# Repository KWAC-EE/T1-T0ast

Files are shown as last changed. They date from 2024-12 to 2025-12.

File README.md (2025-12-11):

# T1-T0ast
Mini-ITX drop-in motherboard for the CM5.

##Rev X4 Issue notice!¡!1!##
If building to RevX4 design spec, depopulate FB6. This component may short -12VDC on PSUs that supply this rail (-12vDC is unused at this time)



Designed with the intention of allowing legacy Sata, PCIE, and ATX/ITX equipment to find a useful home.
Primarily selected components from TI in advance due to open documentation & domestic sourcing.

# Project design files
PCBAs are designed in Altium 22 & 25. This is a paid software platform for professionals, and viewer licenses can be requested from the developers.
Now that the design is roughly complete, I will spend some time learning how to port the design directly into KiCad or EasyEDA for more direct access to hobbyists.
Design references can also be found as PDFs for those who wish to rebuild segments of the design themselves.

# PCBA exports/ Manufacturer files
Designs have been exported as Gerbers with Pick&Place & BOM files such that they may be fully assembled by prototypers such as JLC-PCB, PCB-Way and the like.
Simply upload the zipped project export folder for the PCB, then the internal XLXS/CSV component-level assembly.
Component selection of passives was left generic to allow for flexible sourcing. ICs and other specified parts have a parameter called "LCSC PN", which can be used to preorder components from either LCSC or JLCPCB prior to placing an assembly order.
Some footprints are custom, and part number left unmatched. These have been hand-soldered inhouse or are used for debugging, and I dont recommend having a board house manage these for cost or quality reasons.

# Firmware & Software support
All Hubs are plug&play, and are meant to function with the Raspberry pi CM5 without manual driver installation.
Direct IO is passed from the CM to plug headers without modification.
USB-Audio codec has integrated drivers in Raspberry Pi OS, and Auto-installs via Windows update if accessible.
USB-SATA Bridge requires flashing to the NAND module prior to operation. Hex/bin files to do so are available in corresponding folder.

# License
Copyright Kurt Widhalm/@KWAC-EE 2025
This source describes Open Hardware and is licensed under the CERN-OHL-P v2

You may redistribute and modify this documentation and make products using it under the terms of the CERN-OHL-P v2 (https:/cern.ch/cern-ohl). This documentation is distributed WITHOUT ANY EXPRESS OR IMPLIED WARRANTY, INCLUDING OF MERCHANTABILITY, SATISFACTORY QUALITY AND FITNESS FOR A PARTICULAR PURPOSE. Please see the CERN-OHL-P v2 for applicable conditions

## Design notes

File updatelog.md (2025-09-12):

**2/12/2025**



First rev arrived and I've started preliminary testing. So far, I'm able to confirm that direct passthrough IO (LAN, HDMI, SD Card) function as intended.

HDMI1 (which had a redriver IC) does not function directly, and i'm not sure if its my config file or if i screwed up the icrcuit. Either way, i might omit the redriver from rev x2.

Sadly, my SATA bridges lack the requisite Eeprom to store the firmware required to initialize, so that segement could not be tested. Separate prototypes for this segment are inbound.

The USB Hub chosen for Rev x1 claims to be USB2, but that turns out to be on the low end of the spec (12Mbps) and I wasn't able to get it to populate.

My power scheme (24pin ATX + 4-pin) seems to be working as intended. The momentary switch is superceded by a relay to keep the PSU active once the CM is powered on. At this time, Safe powe-down operation can only be completed from the desktop. Currently powering via Pico-PSU & 12VDC supply for bench setup, but larger PCIE cards/ Sata drives will likely require increased wattage and stability of a full supply.

I've been testing with a CM4 and Radxa-CM5 while i wait for my pi Cm5 (on backorder) so behavior might change when I'm able to switch to the real deal.

**3/7/2025**
Rev X2 updates based on sample testing have been laid out. Development kits for 7x USB2 hub are inbound. SATA bridges have been corrected based on feedback from TI.

Due to differences in startup behavior between rPi & Radxa CM5, hardwired delay circuits have been added to latching relays, and power button/reset have been made discrete.

Previous assembly process called out ENIG for PCB; will switch to HASL to save cost

**4/25/2025**
Rev X3 samples received and modified during testing.



All IO EXCEPT for the M.2 & Sata behave as intended.

TUSB9261 GRST circuit needed to be modified to allow for passive reset operation during boot. Firmware for these chips also needed to be applied externally to their requisiste SPI flash modules with a clip programmer, as TI no longer supports the flashing utility in Linux.

The TUSB8020 Hub used to drive the USB-SATA bridges is having issues. lsusb shows internal PID 8027 enumerated, but not the 8025 segment. For some reason, this means the downstream ports aren't initialised by the system.
I can't tell at the moment if this is due to a hardware fault in the pinout of the chip or the pi, or if theres too much interference from running the DP/DM traces under nearby AC caps.

The Sata bridge used for the M.2 slot initialises just fine, but I can't seem to get it to recognise an A+M key sata drive. Maybe something in the 3.3V power scheme? I'll shunt over the resettable fuse to see if it is just dropping too much voltage.

Tested several simple PCIe devices in the x16 slot like a SATA expansion and USB-C expansion card, and both are recognised by lspci. Both seem to function as intended, but thats at PCIe gen 2 speeds (haven't modified the config to try Gen 3).
A low end graphics (GT210) card i dropped in wasn't recognised by lspci, so I can't vouch for that kind of implementation just yet.

Feels like i'm nearing the finish line. In any case, the X3 does most of what i need for work purposes, so I may spend some time away from development.

**5/8/2025**
 Rev X4 changes underway
 
I've removed the manually timed reset circuits for the latching relay and Sata bridges, and made them passive. The leveling capacitors on the TUSB9261s are larger than recommended, with the intention of delaying reset until 2x the time of their host USB3 hubs.

I've also removed & replaced the TUSB8020 with an 8041 for the sata bridges, routing the spare USB3 lanes to a FP-IO header.

Per TI's recommendations, I've added AC coupling caps on BOTH the RX & TX lines between the pi and hubs. The IO board for the CM5 lacks these and seem to function ok, but in the interest of Giving myself an out, i will at least include the pads (couple replace RX caps with 0ohm resistors if deemed unnecessary)

Biffed the firmware flashing process and my flashing tool during debugging, hopefully will receive replacement chip-clips soon. Ideally, i could pre-flash the spi modules before doing a full build, but the bridges on the full board dont seem to like receiving rev 1.06 firmware binaries as much as their discrete counterparts on my dev kits. what this means is that I will need to port windows to a CM5 (WoP project has thankfully done enough for me to try this) and use the native TI Flash-burner utility to do this within the system.

but holy hell, i reran the costs for this dev build, and its over a grand for 5 boards from JLCPCB with the nonsensical tarrifs (domestics are much higher and have MOQ of 10, which i think is even more wasteful if a batch is a dud).
If you don't see an update from me after this, its because i've mothballed development until a sane adult is in charge.

**6/4/2025**
Well, here i am. Bit the bullet. one more go from me, fam

Rev X4 with some IO modifications is in flight. If this doesn't work, i entrust the next weary traveler to pick up the torch and carry on.

results to follow

**6/30/2025**
Works as well as I can reasonably hope. had to remove the AC caps to leave both RX & TX floating on the hub which drives the 2 sata bridges.

Been troubleshooting this issue so long, with tickets to both TI & The pi forums, and i cant find a solution to the USB3 enumeration issue.

I'll package and release the current hardware production files once I daily drive this model for a bit. Sent a sample for review, so if that brought you here, welcome!

Don't take my design as gospel, but it is all at least 98% functional, from the power regulation to the IO expanders and adapters. If you have a project which could use part of this design, adherent to the open-source nature of the project as it is, have at it.

If you need design resources, or you're interested in seeing which hardware can be made compatible with this platform, check out my other repositories.

**9/12/2025**
The whole thing works. I am an idiot.

The CM5's that I'd been using for development and testing were all damaged in the same location by me, and I never noticed until an rPi dev pointed out that part of the usb3 circuit had components close to a mounting hole.

After NOT fucking up a fresh CM and installing it fresh out of the box, everything worked as designed. so there. I'll be done.

Pending review from some connoisseurs, I'll uprev and package the files in an official release, but I'm not puting myself under any pressure to do so.

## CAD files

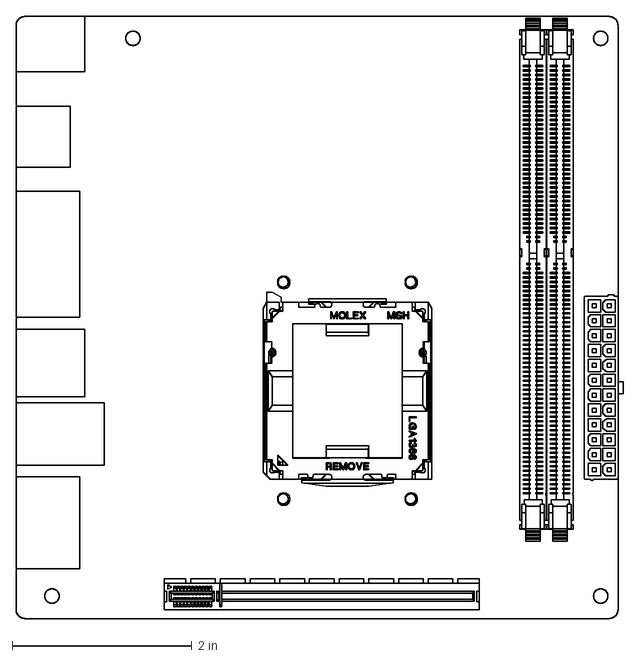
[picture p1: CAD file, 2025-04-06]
Altium Project/X1/Mini-ITX Mobo.step.DXF
6.75 x 6.69 in

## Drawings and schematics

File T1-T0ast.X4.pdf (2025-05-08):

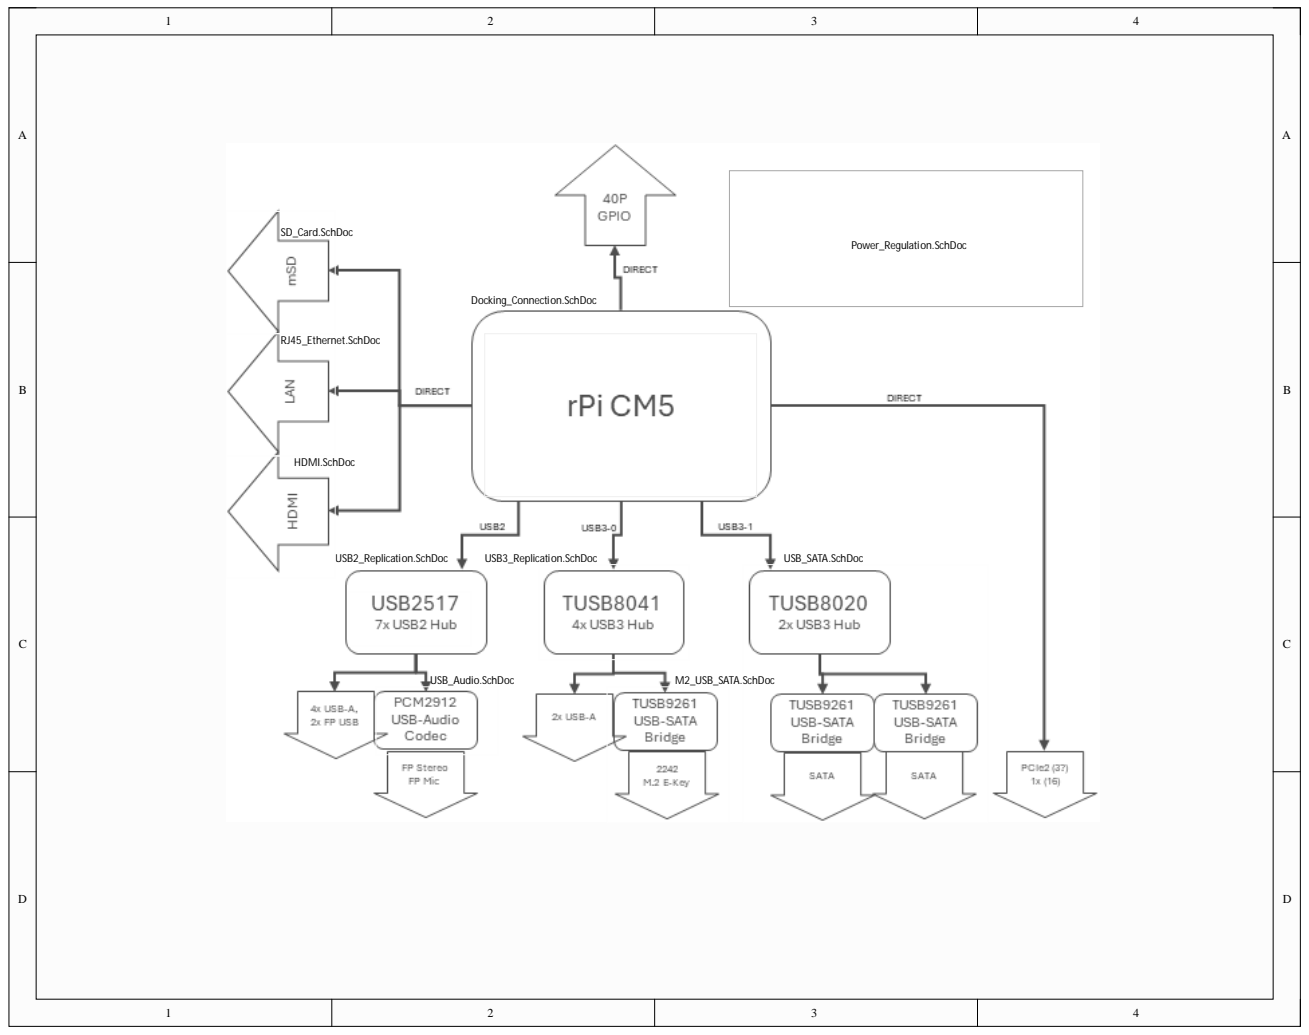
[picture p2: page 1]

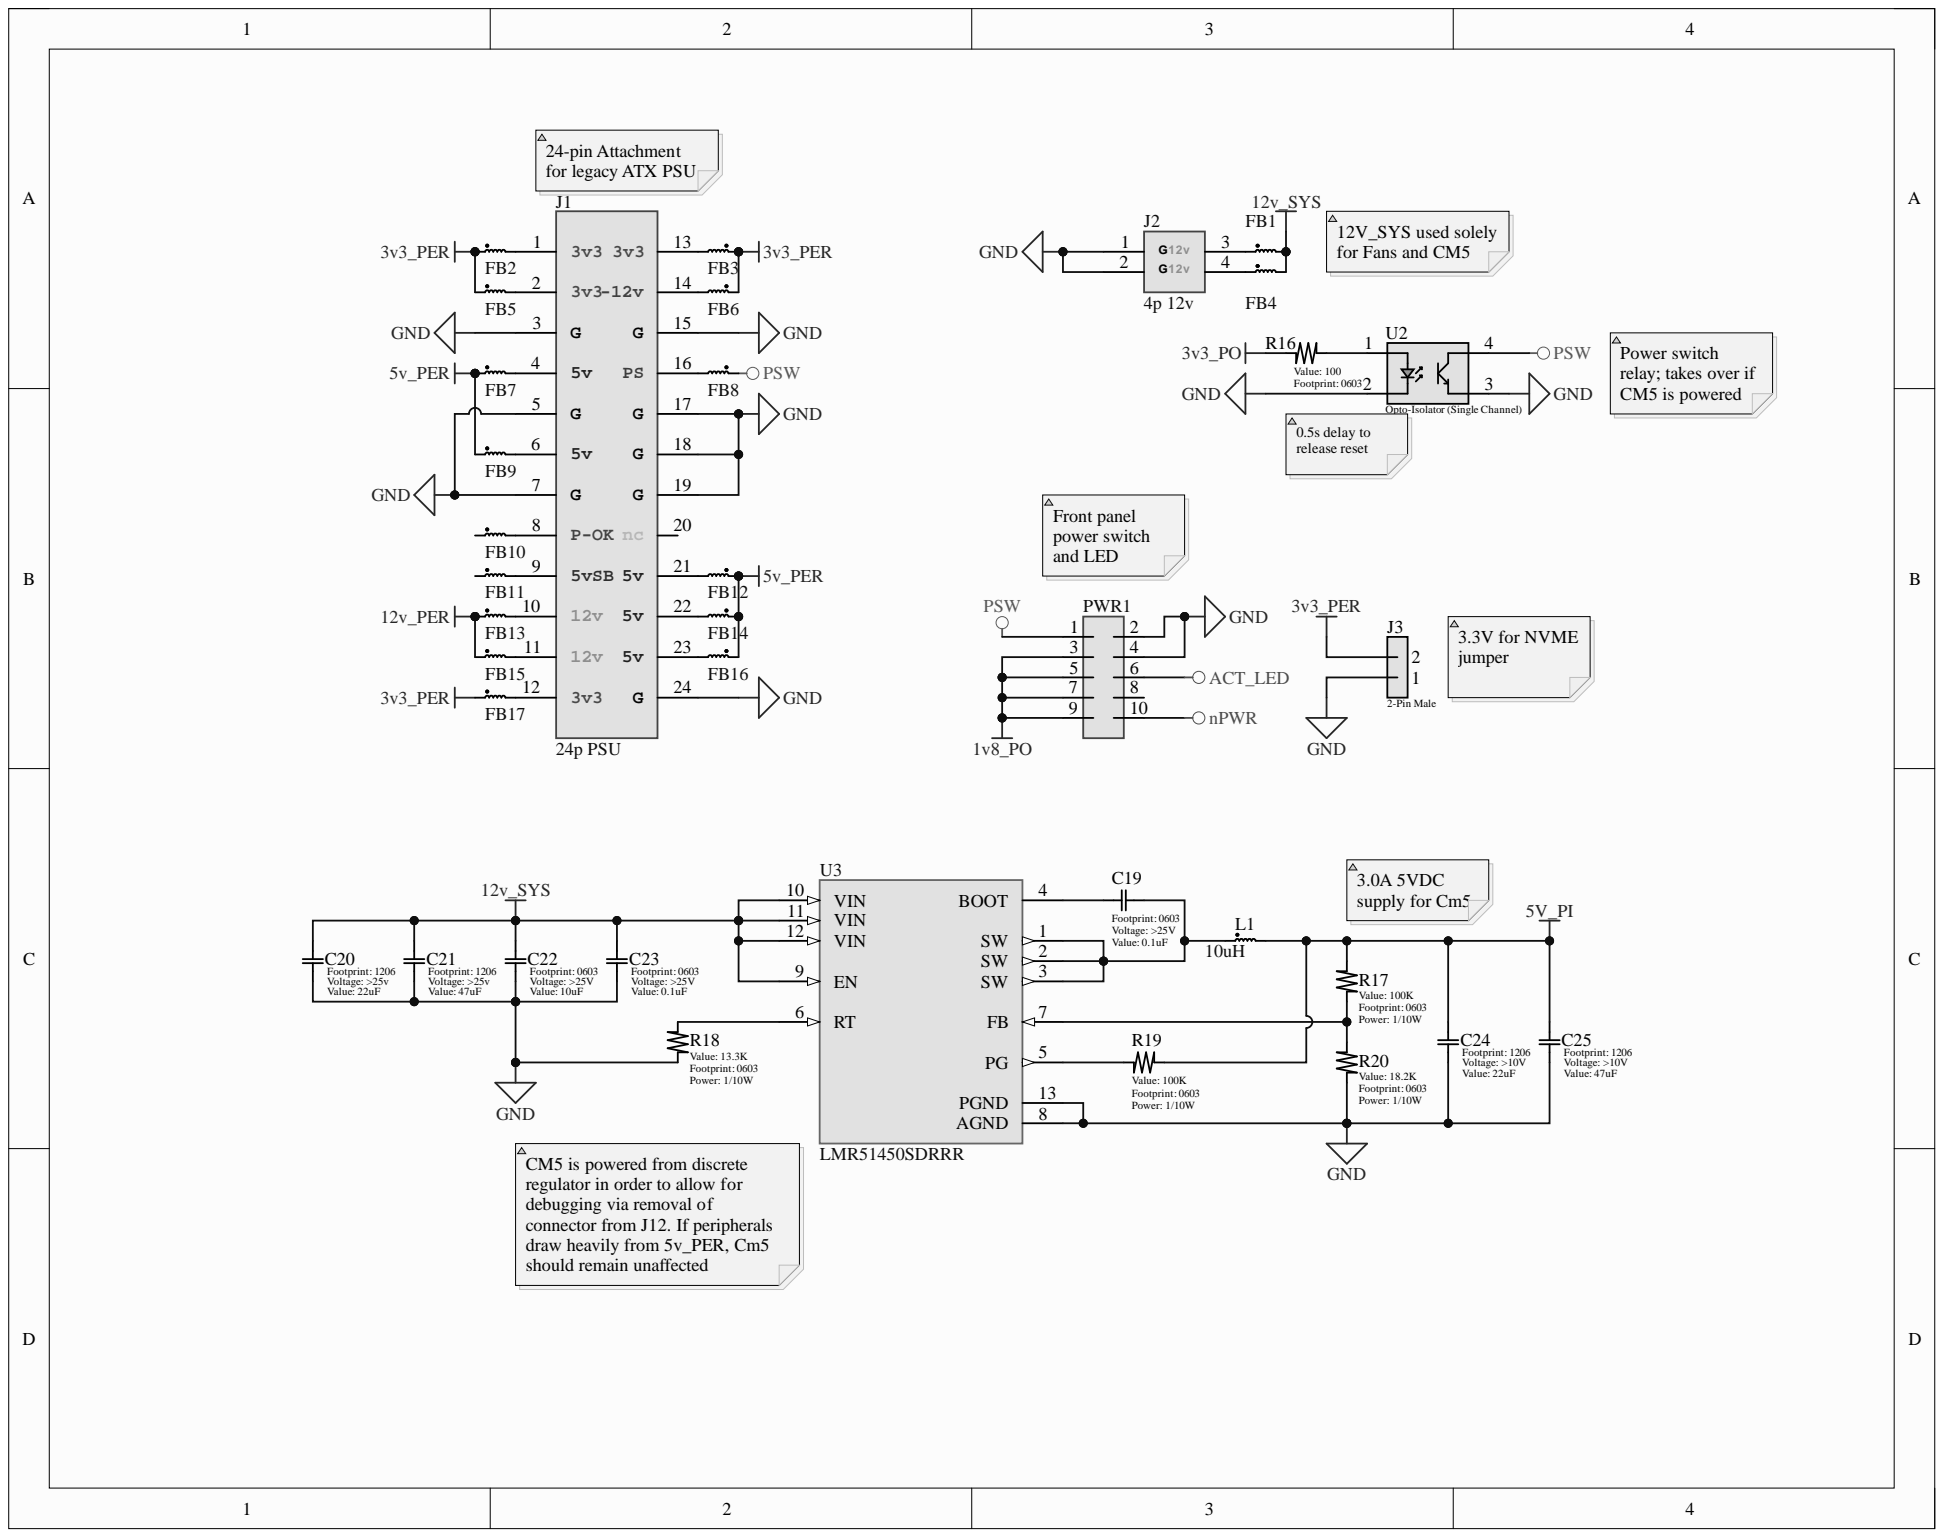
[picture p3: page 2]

24-pin Attachment
for legacy ATX PSU

Power switch
relay; takes over if
CM5 is powered

Opto-Isolator (Single Channel)

CM5 is powered from discrete
regulator in order to allow for
debugging via removal of
connector from J12. If peripherals
draw heavily from 5v_PER, Cm5
should remain unaffected

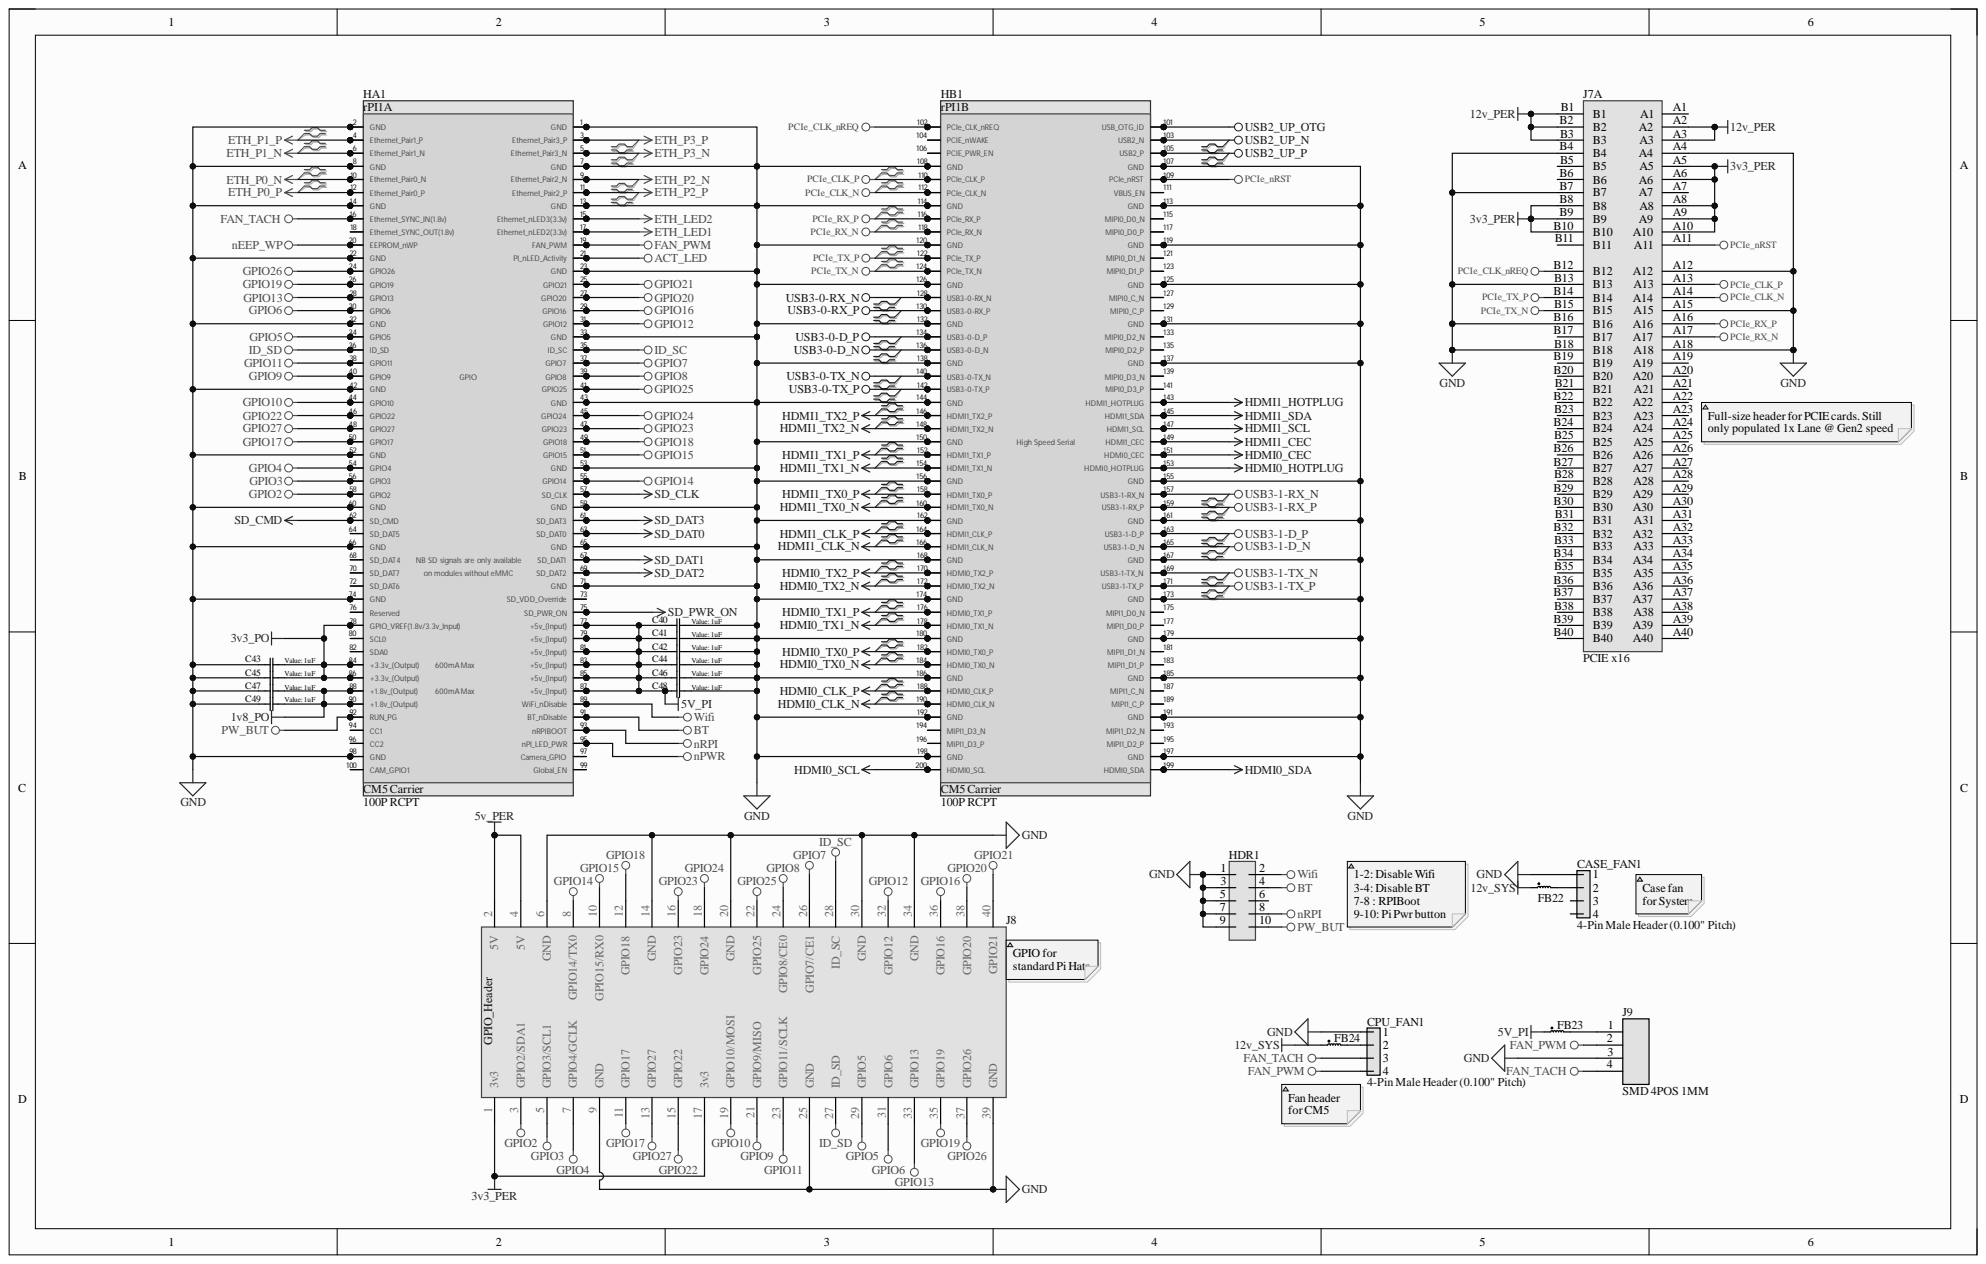
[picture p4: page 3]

PCIe_CLK_nREQ | B8 B8

Full-size headerfor PCIEcards. Still
only populated 1x Lane @ Gen2 speed

NB SD signals are only available
on modules without eMMC

4-Pin Male Header(0.100" Pitch)

GPIO3 GPIO4 | GPIO27 GPIO22

GPIO9 GPIO11 | GPIO6

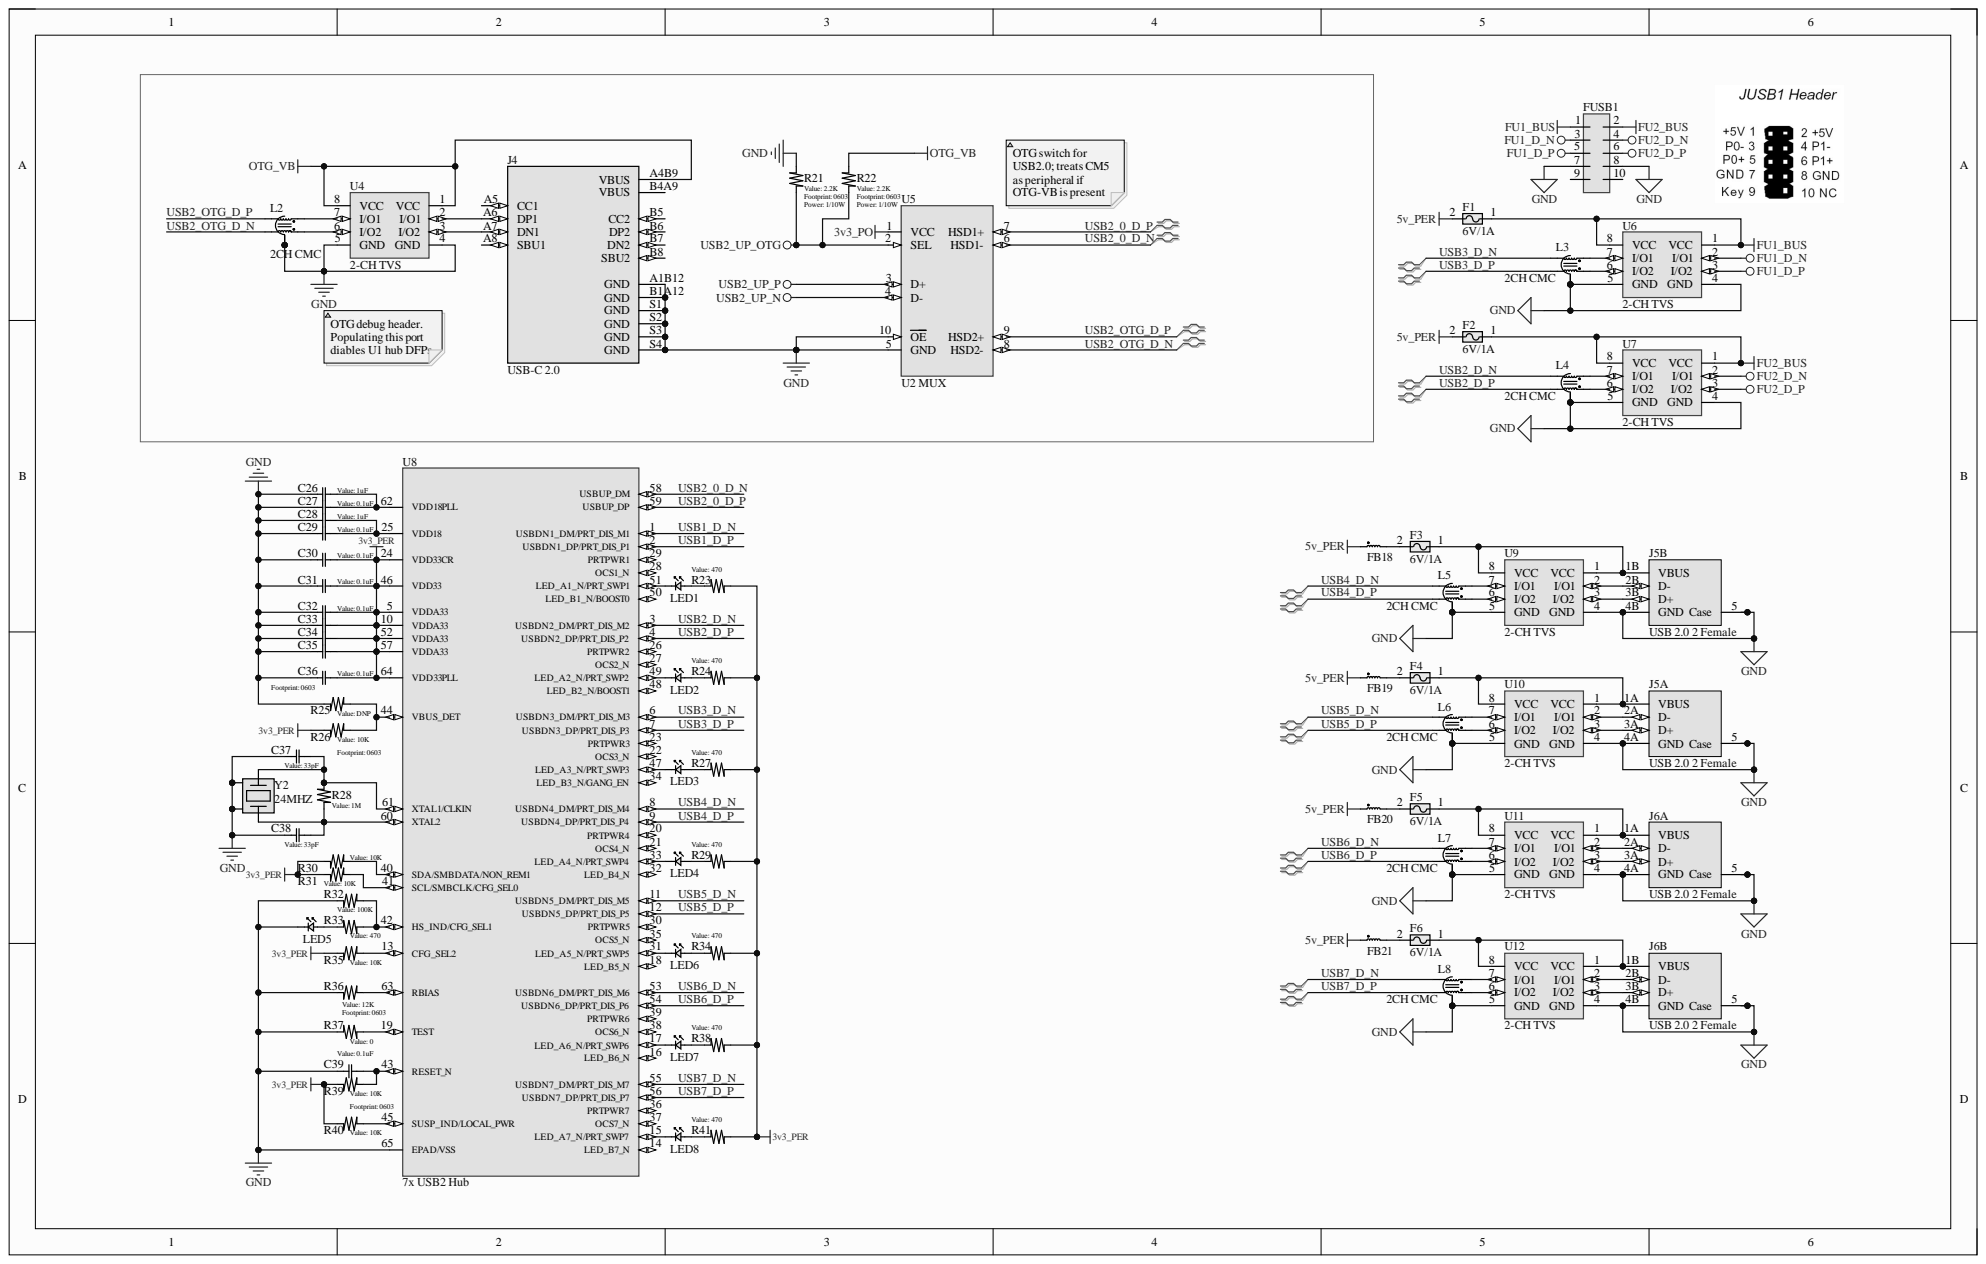
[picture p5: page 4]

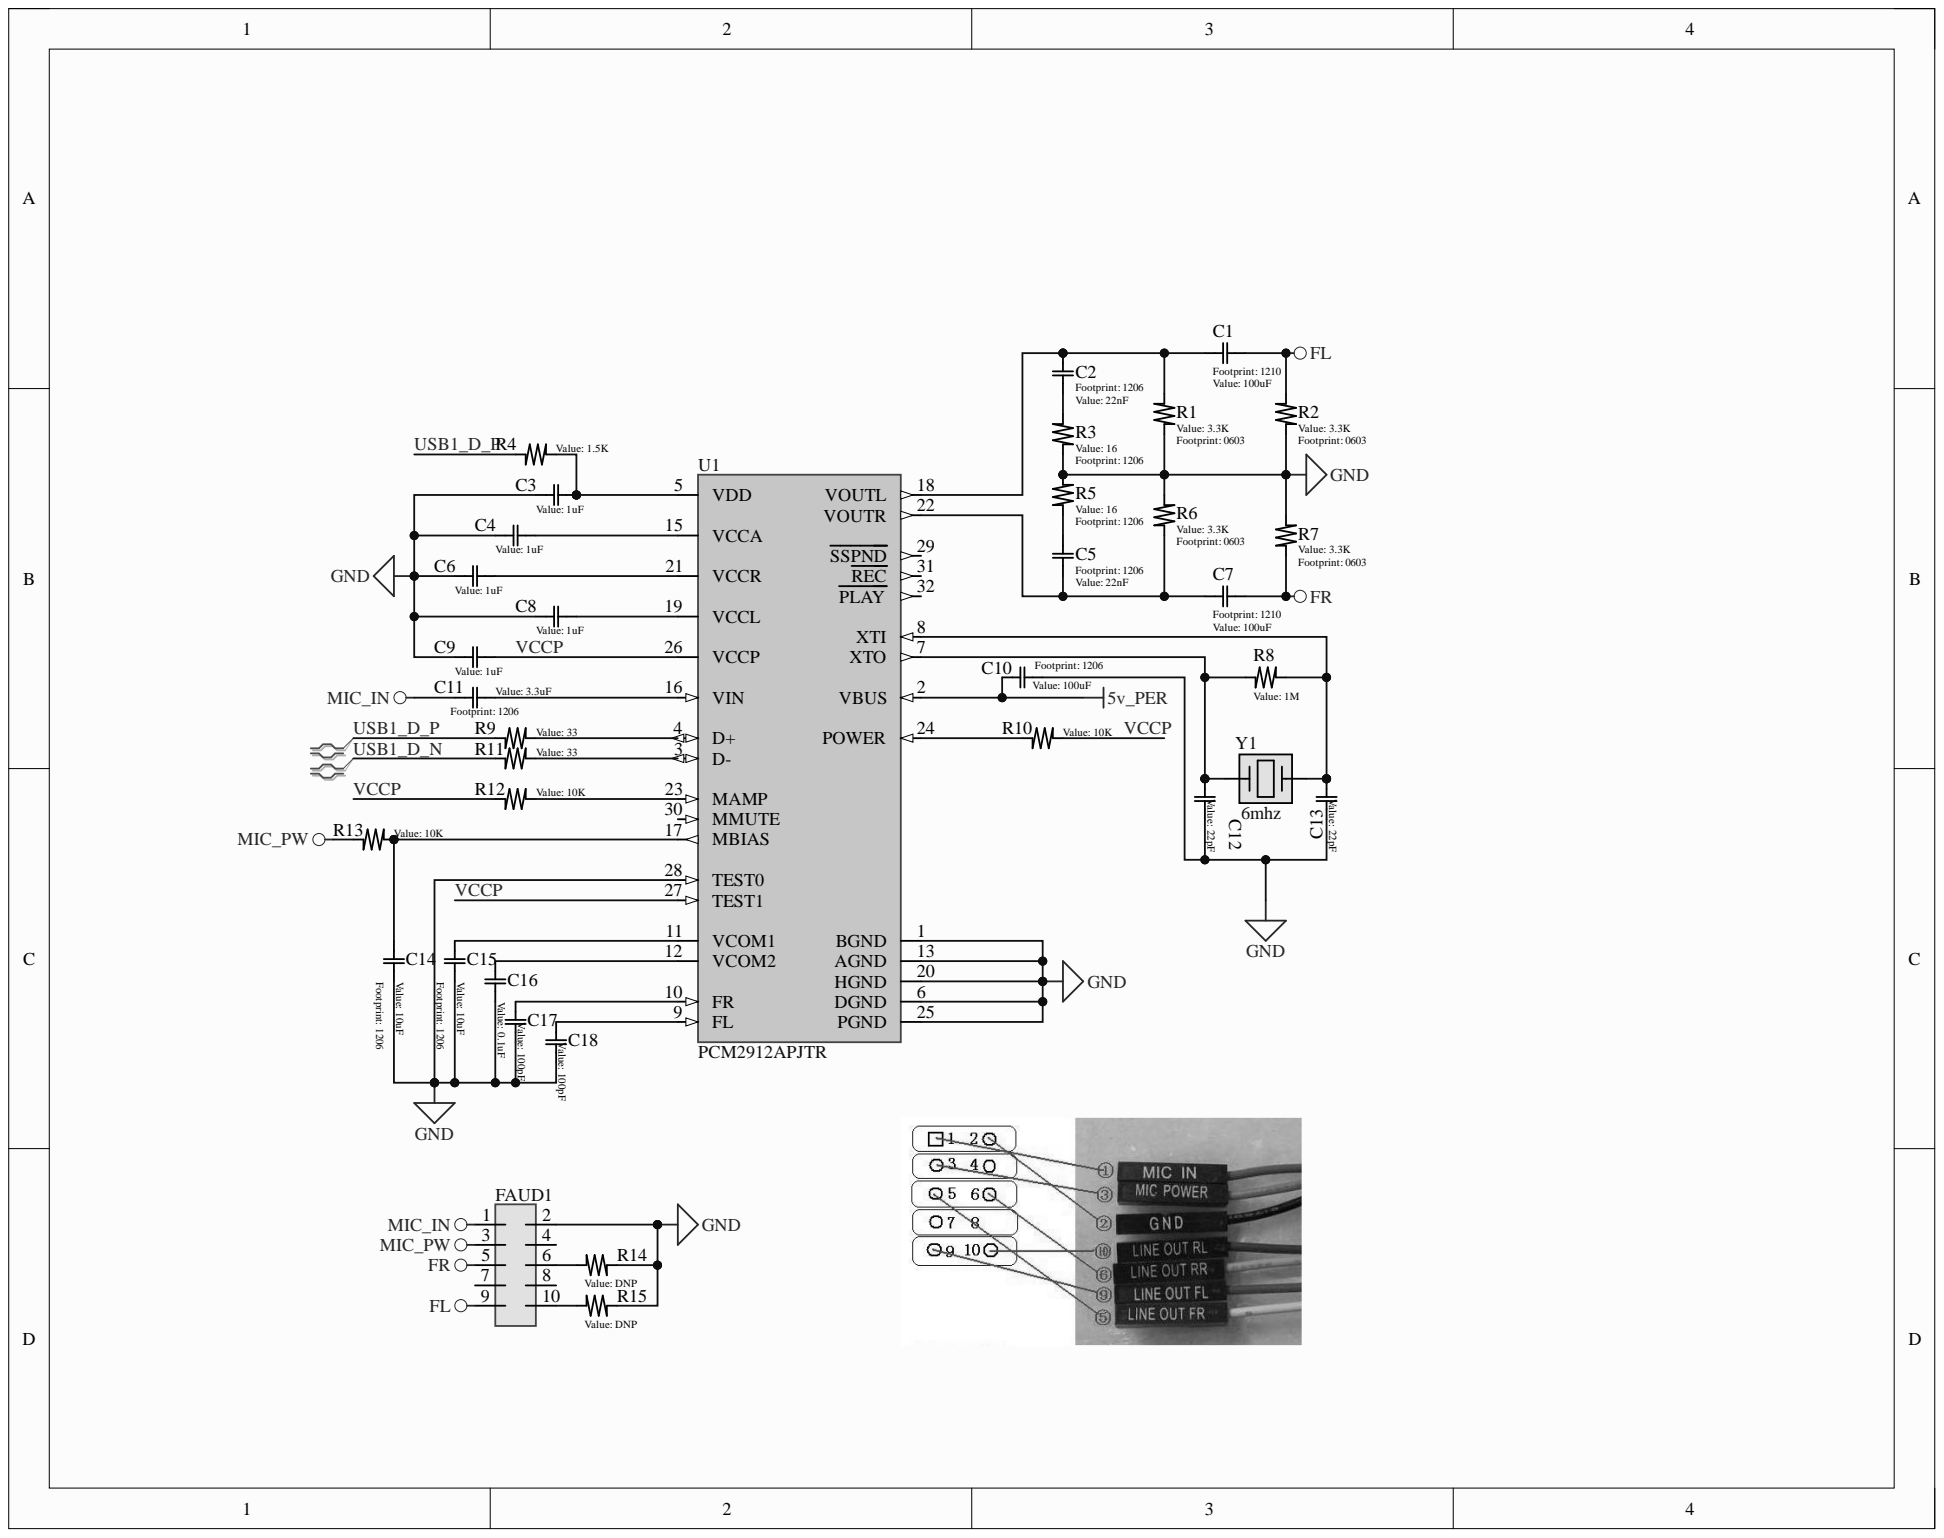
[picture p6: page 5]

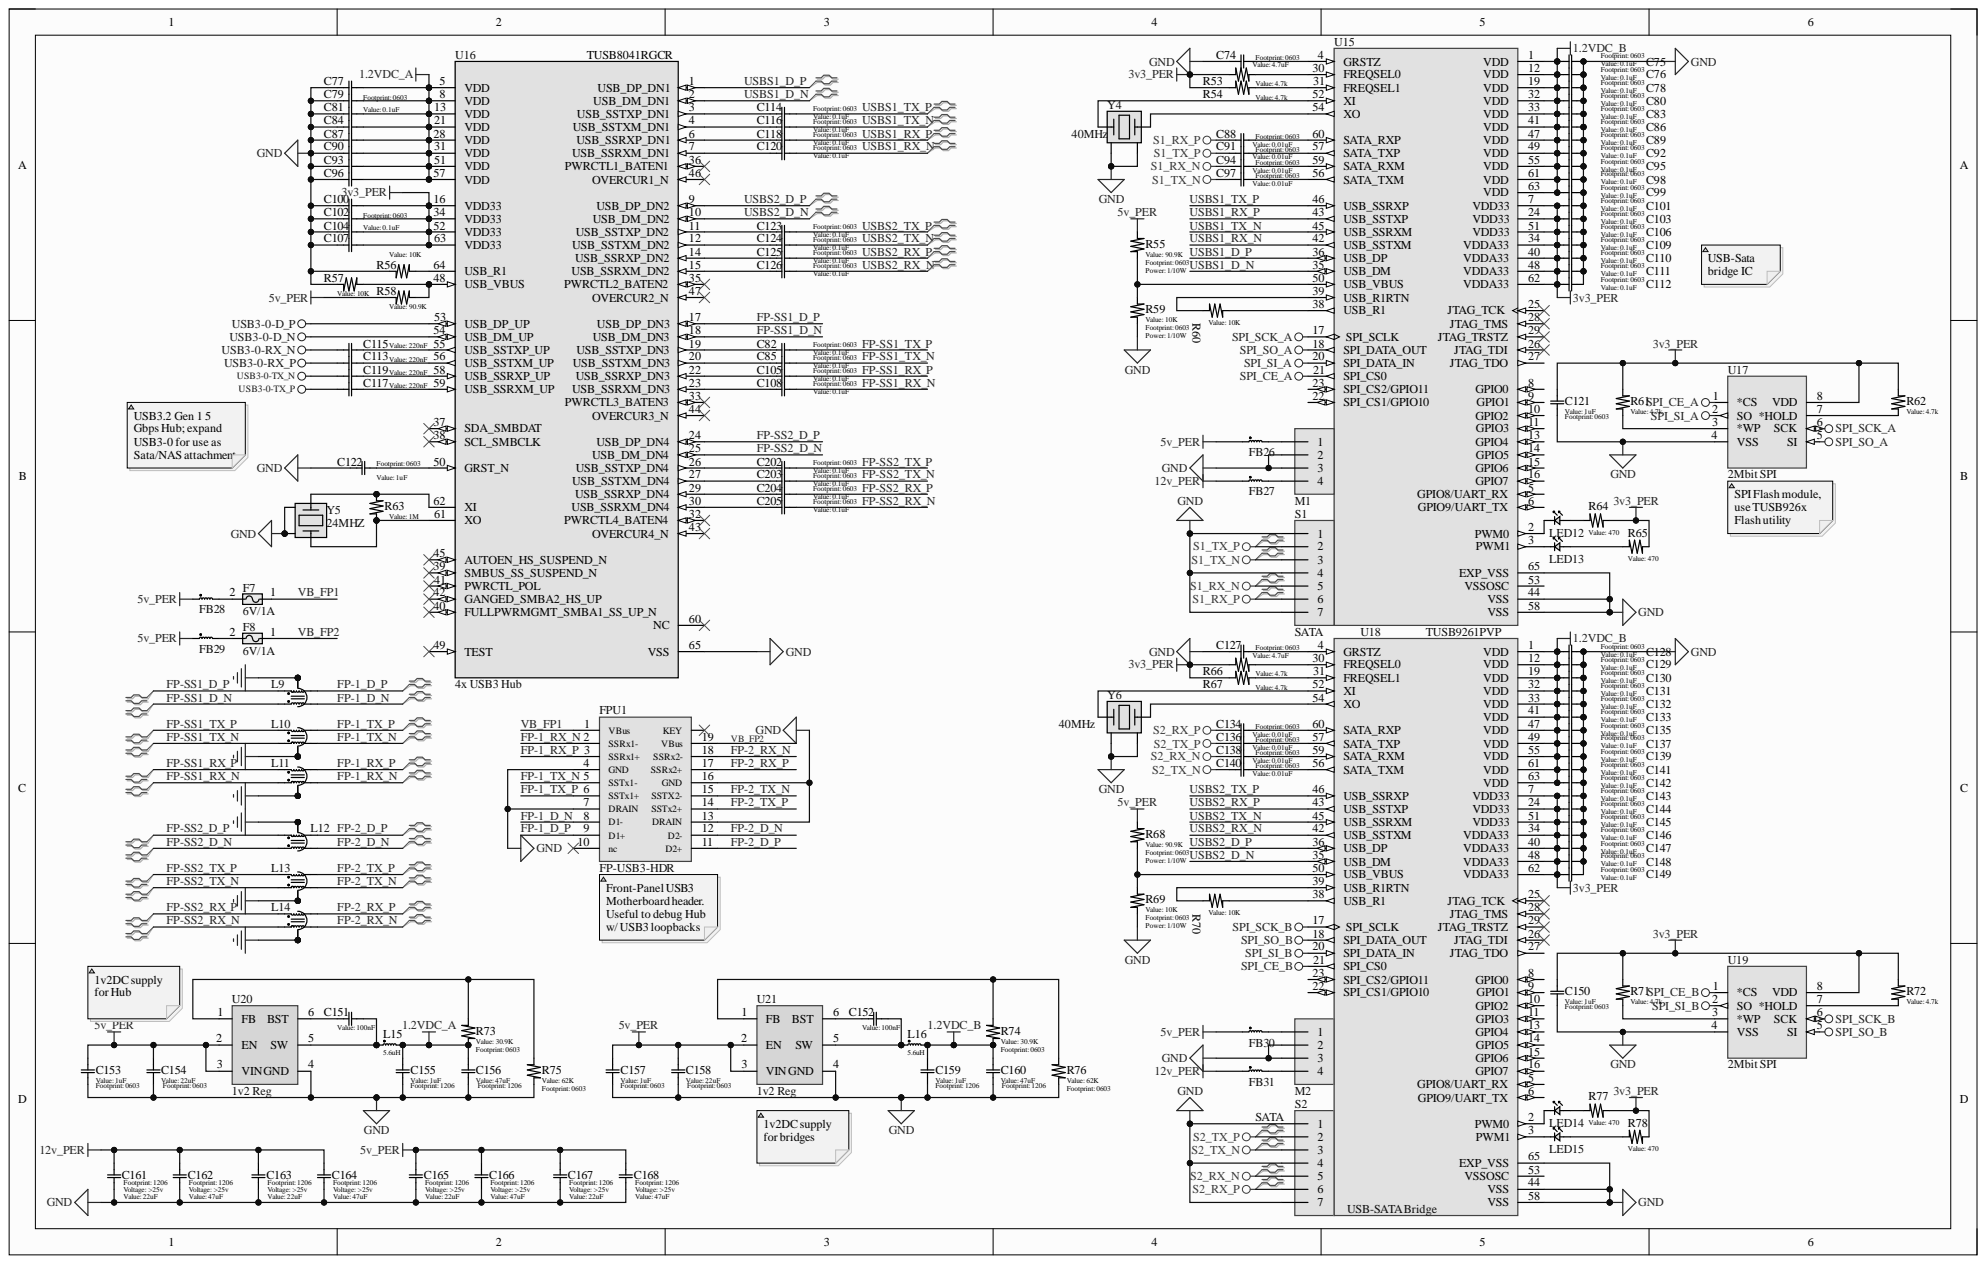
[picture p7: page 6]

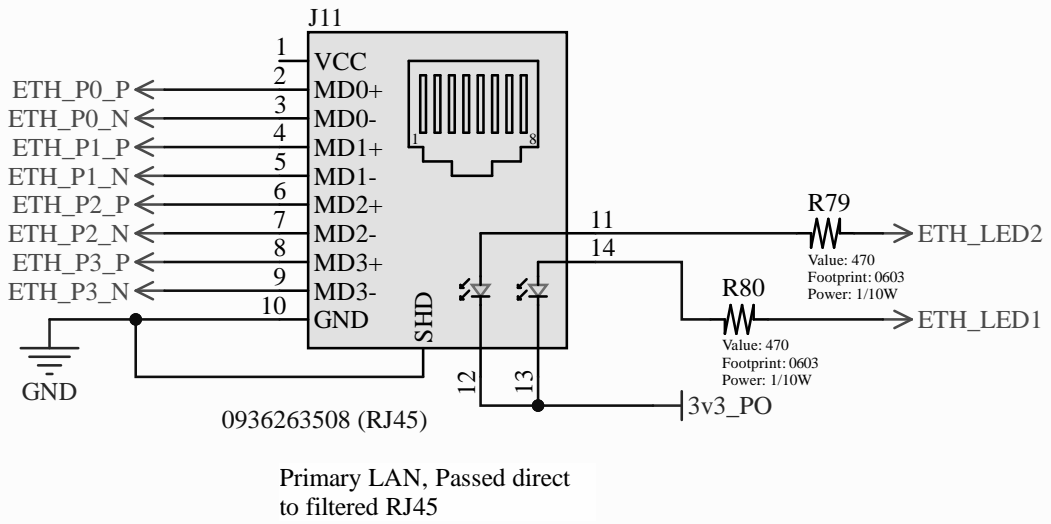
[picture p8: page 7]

Primary LAN, Passed direct
to filtered RJ45

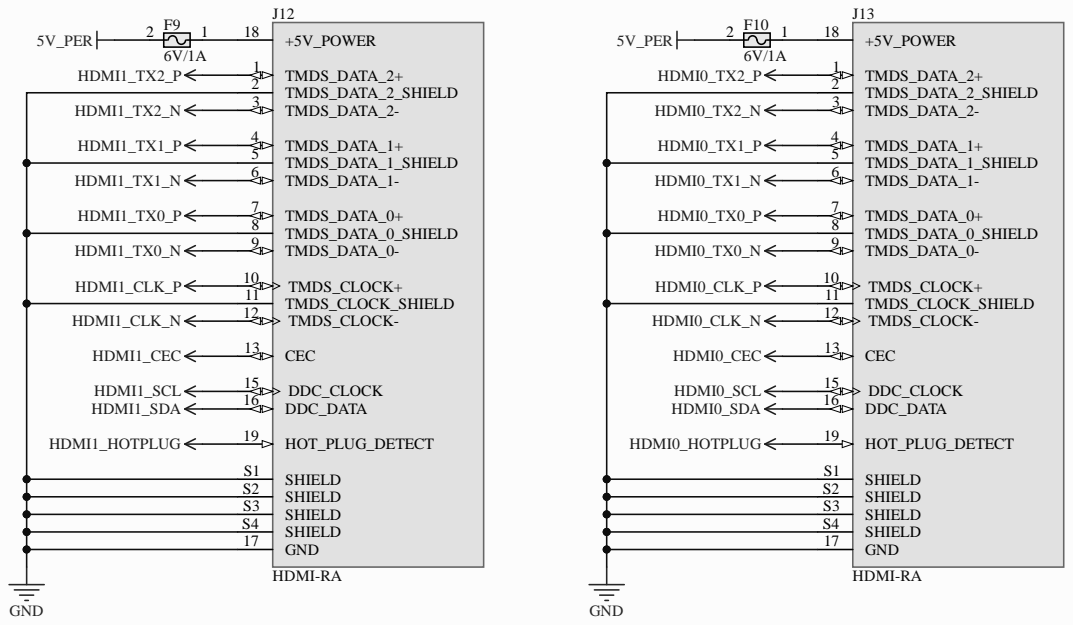
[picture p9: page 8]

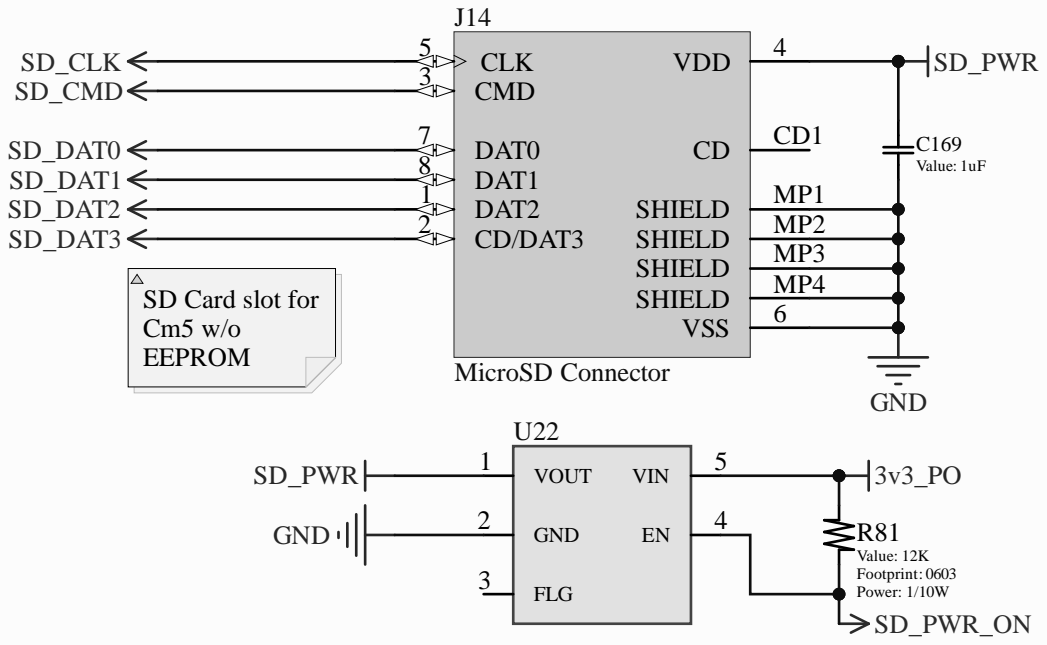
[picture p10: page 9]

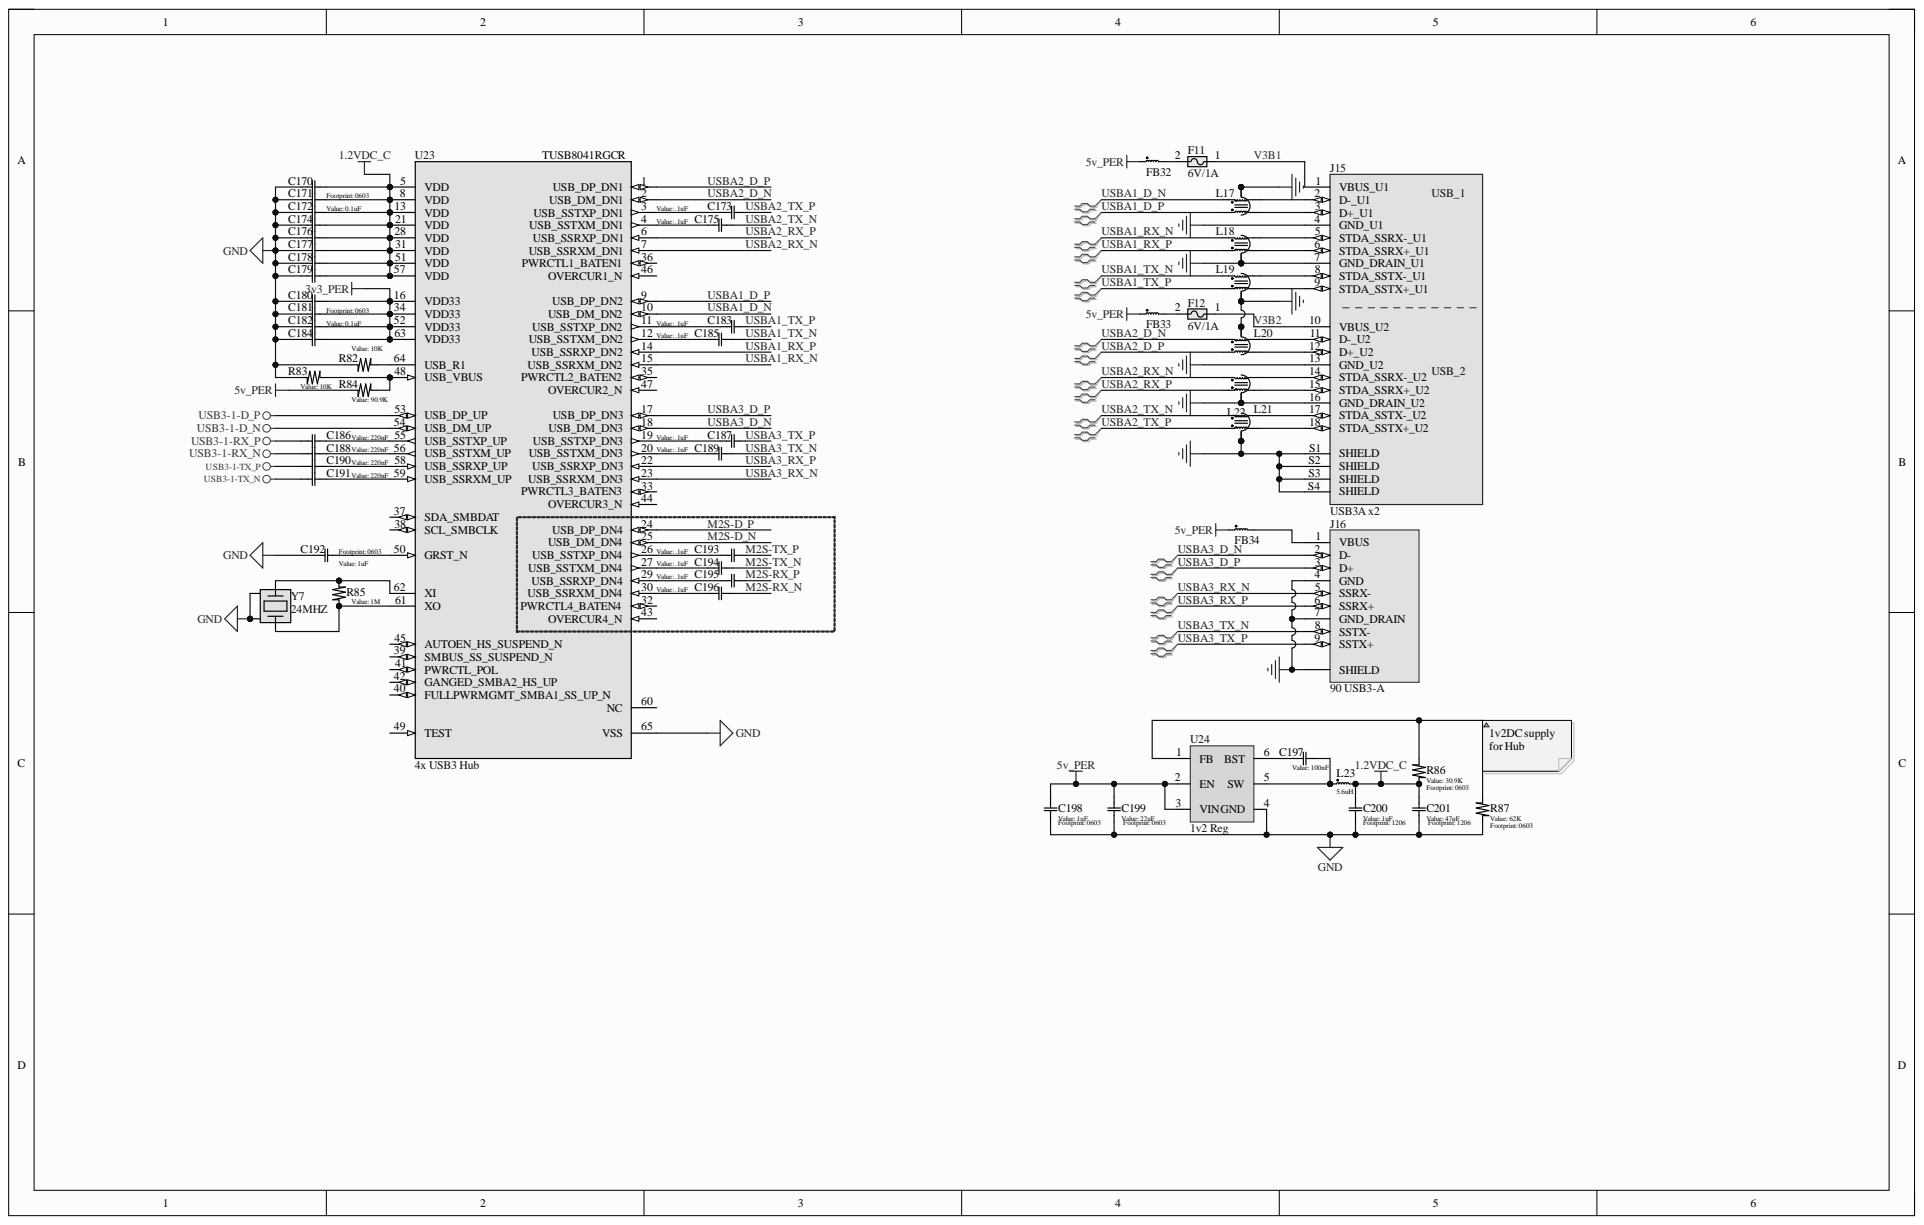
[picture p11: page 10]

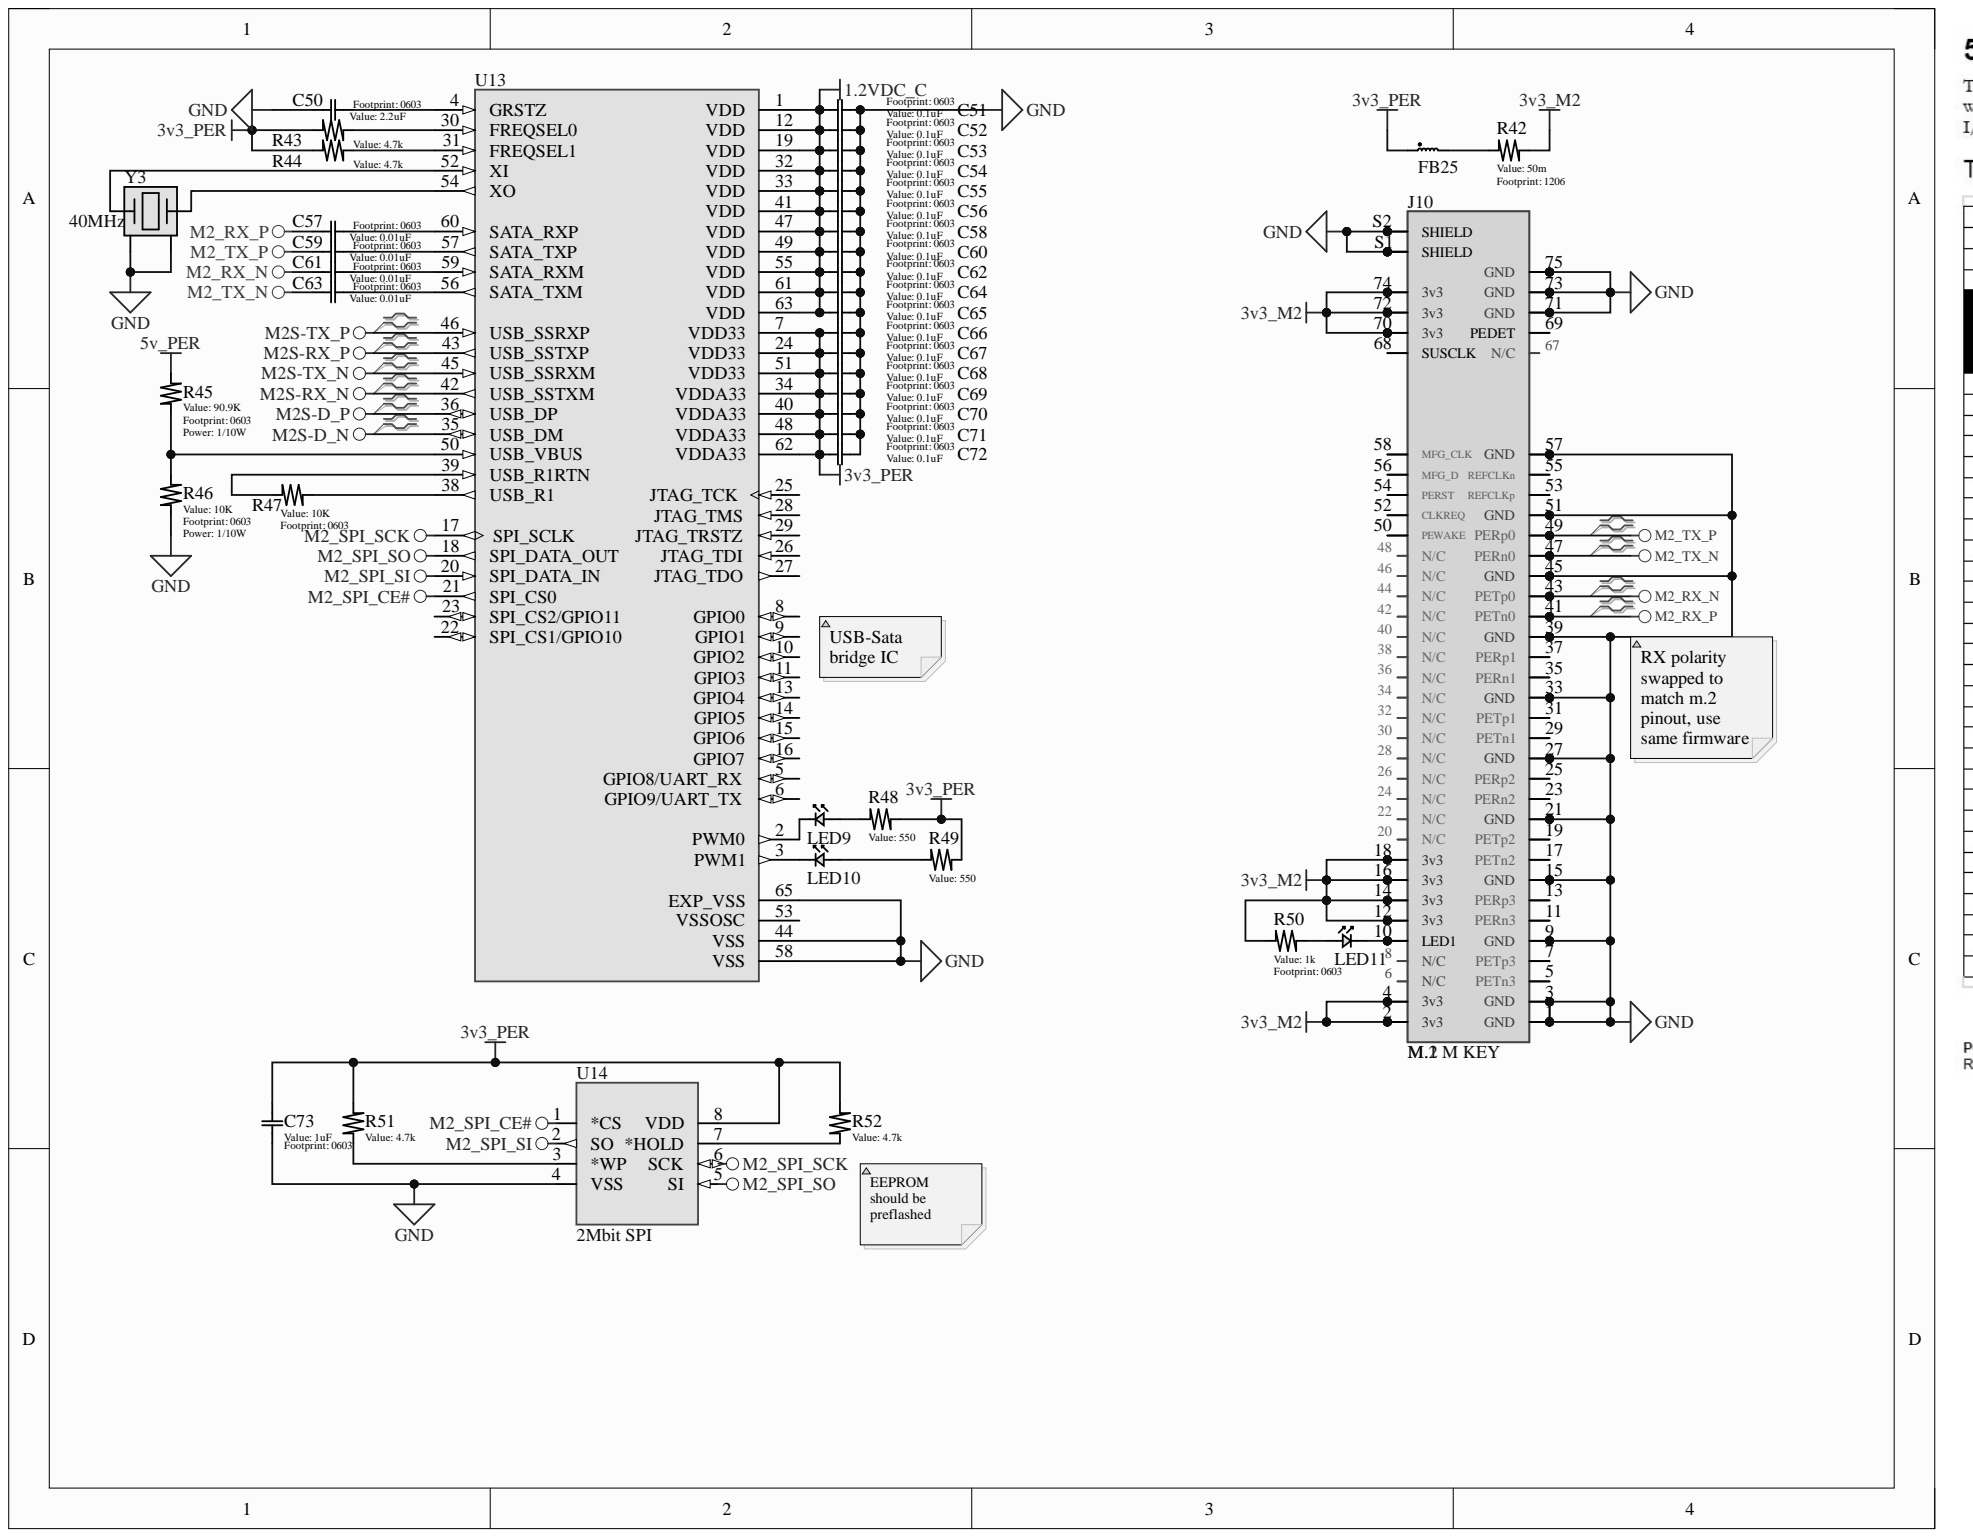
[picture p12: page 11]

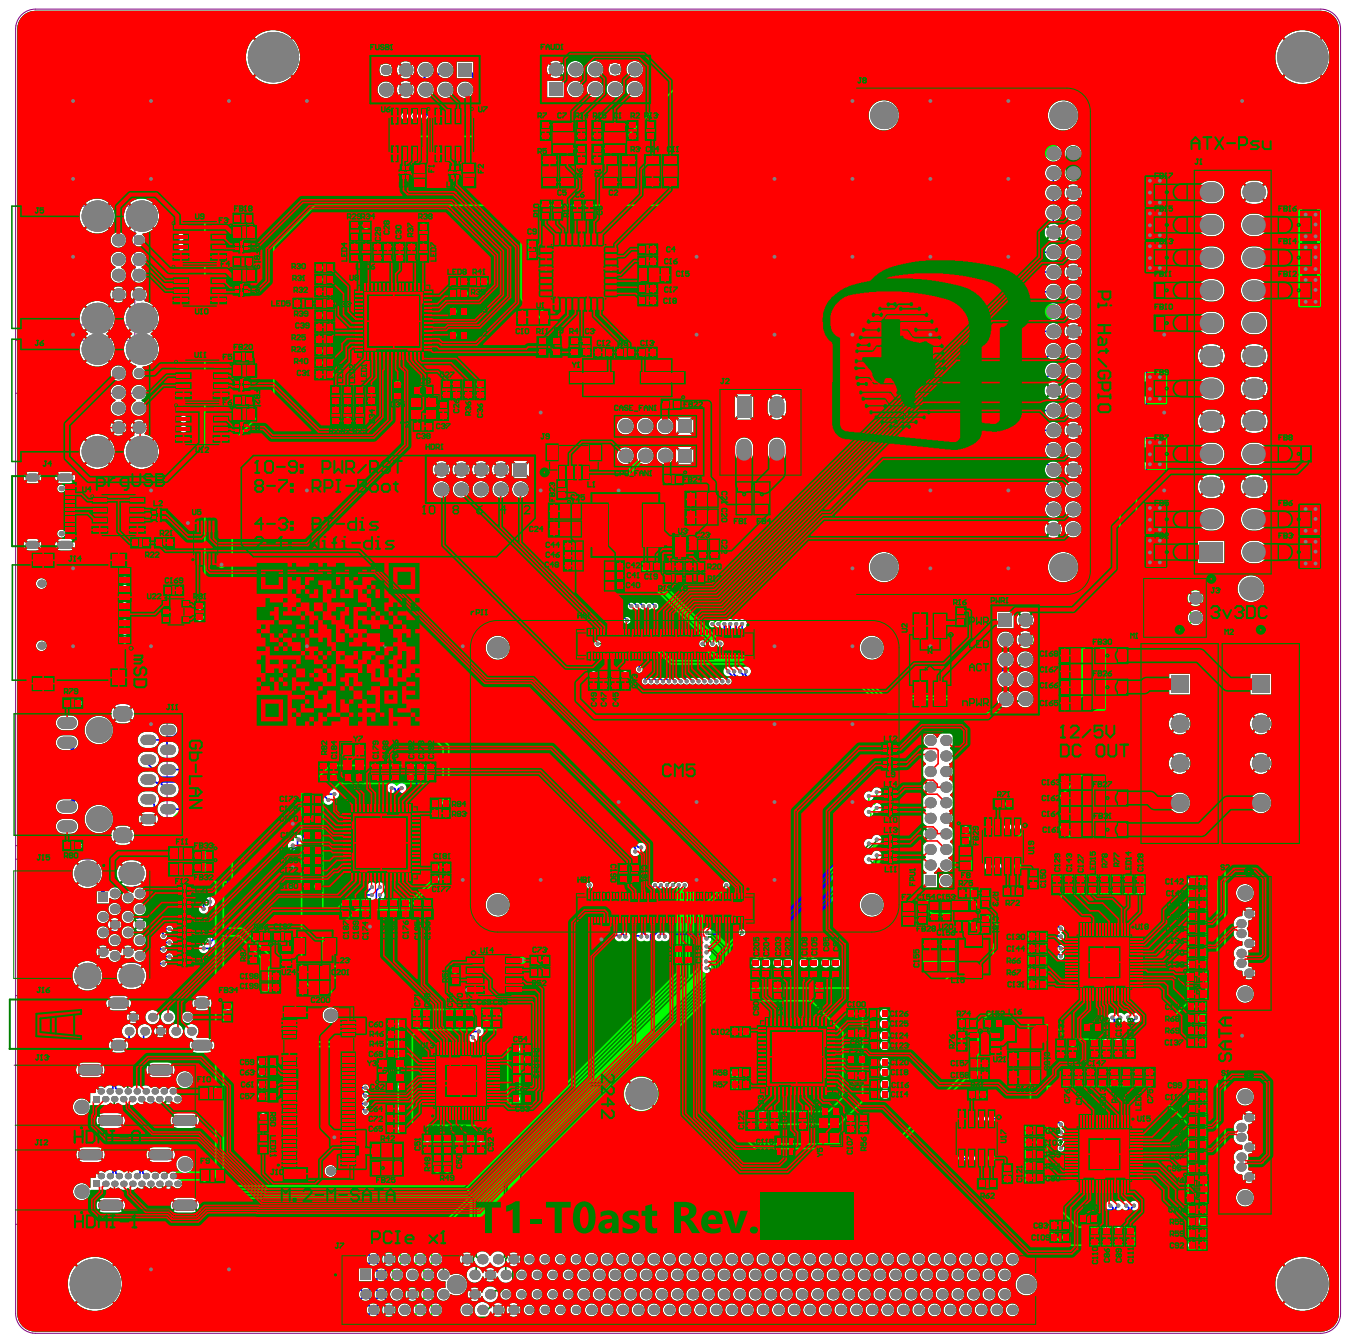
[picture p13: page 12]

Designator | LCSCPN | Footprint | Value
C1 | | 1210 | 100uF
C2 | | 1206 | 22nF
C3 | | 0603 | 1uF
C4 | | 0603 | 1uF
C5 | | 1206 | 22nF
C6 | | 0603 | 1uF
C7 | | 1210 | 100uF
C8 | | 0603 | 1uF
C9 | | 0603 | 1uF
C10 | | 1206 | 100uF
C11 | | 1206 | 3.3uF
C12 | | 0603 | 22pF
C13 | | 0603 | 22pF
C14 | | 1206 | 10uF
C15 | | 1206 | 10uF
C16 | | 0603 | 0.1uF
C17 | | 0603 | 100pF
C18 | | 0603 | 100pF
C19 | | 0603 | 0.1uF
C20 | | 1206 | 22uF
C21 | | 1206 | 47uF
C22 | | 0603 | 10uF
C23 | | 0603 | 0.1uF
C24 | | 1206 | 22uF
C25 | | 1206 | 47uF
C26 | | 0603 | 1uF
C27 | | 0603 | 0.1uF
C28 | | 0603 | 1uF
C29 | | 0603 | 0.1uF
C30 | | 0603 | 0.1uF
C31 | | 0603 | 0.1uF
C32 | | 0603 | 0.1uF
C33 | | 0603 | 0.1uF
C34 | | 0603 | 0.1uF
C35 | | 0603 | 0.1uF
C36 | | 0603 | 0.1uF
C37 | | 0603 | 33pF
C38 | | 0603 | 33pF
C39 | | 0603 | 0.1uF
C40 | | 0603 | 1uF
C41 | | 0603 | 1uF
C42 | | 0603 | 1uF
C43 | | 0603 | 1uF
C44 | | 0603 | 1uF
C45 | | 0603 | 1uF
C46 | | 0603 | 1uF
C47 | | 0603 | 1uF
C48 | | 0603 | 1uF
C49 | | 0603 | 1uF
C50 | | 0603 | 2.2uF
C51 | | 0603 | 0.1uF
C52 | | 0603 | 0.1uF
C53 | | 0603 | 0.1uF
C54 | | 0603 | 0.1uF
C55 | | 0603 | 0.1uF
C56 | | 0603 | 0.1uF
C57 | | 0603 | 0.01uF
C58 | | 0603 | 0.1uF
C59 | | 0603 | 0.01uF
C60 | | 0603 | 0.1uF
C61 | | 0603 | 0.01uF
C62 | | 0603 | 0.1uF
C63 | | 0603 | 0.01uF
C64 | | 0603 | 0.1uF
C65 | | 0603 | 0.1uF
C66 | | 0603 | 0.1uF
C67 | | 0603 | 0.1uF
C68 | | 0603 | 0.1uF
C69 | | 0603 | 0.1uF
C70 | | 0603 | 0.1uF
C71 | | 0603 | 0.1uF
C72 | | 0603 | 0.1uF
C73 | | 0603 | 1uF
C74 | | 0603 | 4.7uF
C75 | | 0603 | 0.1uF
C76 | | 0603 | 0.1uF
C77 | | 0603 | 0.1uF
C78 | | 0603 | 0.1uF
C79 | | 0603 | 0.1uF
C80 | | 0603 | 0.1uF
C81 | | 0603 | 0.1uF
C82 | | 0603 | 0.1uF
C83 | | 0603 | 0.1uF
C84 | | 0603 | 0.1uF
C85 | | 0603 | 0.1uF
C86 | | 0603 | 0.1uF
C87 | | 0603 | 0.1uF
C88 | | 0603 | 0.01uF
C89 | | 0603 | 0.1uF
C90 | | 0603 | 0.1uF
C91 | | 0603 | 0.01uF
C92 | | 0603 | 0.1uF
C93 | | 0603 | 0.1uF
C94 | | 0603 | 0.01uF
C95 | | 0603 | 0.1uF
C96 | | 0603 | 0.1uF
C97 | | 0603 | 0.01uF
C98 | | 0603 | 0.1uF
C99 | | 0603 | 0.1uF
C100 | | 0603 | 0.1uF
C101 | | 0603 | 0.1uF
C102 | | 0603 | 0.1uF
C103 | | 0603 | 0.1uF
C104 | | 0603 | 0.1uF
C105 | | 0603 | 0.1uF
C106 | | 0603 | 0.1uF
C107 | | 0603 | 0.1uF
C108 | | 0603 | 0.1uF
C109 | | 0603 | 0.1uF
C110 | | 0603 | 0.1uF
C111 | | 0603 | 0.1uF
C112 | | 0603 | 0.1uF
C113 | | 0603 | 220nF
C114 | | 0603 | 0.1uF
C115 | | 0603 | 220nF
C116 | | 0603 | 0.1uF
C117 | | 0603 | 220nF
C118 | | 0603 | 0.1uF
C119 | | 0603 | 220nF
C120 | | 0603 | 0.1uF
C121 | | 0603 | 1uF
C122 | | 0603 | 1uF
C123 | | 0603 | 0.1uF
C124 | | 0603 | 0.1uF
C125 | | 0603 | 0.1uF
C126 | | 0603 | 0.1uF
C127 | | 0603 | 4.7uF
C128 | | 0603 | 0.1uF
C129 | | 0603 | 0.1uF
C130 | | 0603 | 0.1uF
C131 | | 0603 | 0.1uF
C132 | | 0603 | 0.1uF
C133 | | 0603 | 0.1uF
C134 | | 0603 | 0.01uF
C135 | | 0603 | 0.1uF
C136 | | 0603 | 0.01uF
C137 | | 0603 | 0.1uF
C138 | | 0603 | 0.01uF
C139 | | 0603 | 0.1uF
C140 | | 0603 | 0.01uF
C141 | | 0603 | 0.1uF
C142 | | 0603 | 0.1uF
C143 | | 0603 | 0.1uF
C144 | | 0603 | 0.1uF
C145 | | 0603 | 0.1uF
C146 | | 0603 | 0.1uF
C147 | | 0603 | 0.1uF
C148 | | 0603 | 0.1uF
C149 | | 0603 | 0.1uF
C150 | | 0603 | 1uF
C151 | | 0603 | 100nF
C152 | | 0603 | 100nF
C153 | | 0603 | 1uF
C154 | | 0603 | 22uF
C155 | | 1206 | 1uF
C156 | | 1206 | 47uF
C157 | | 0603 | 1uF
C158 | | 0603 | 22uF
C159 | | 1206 | 1uF
C160 | | 1206 | 47uF
C161 | | 1206 | 22uF
C162 | | 1206 | 47uF
C163 | | 1206 | 22uF
C164 | | 1206 | 47uF
C165 | | 1206 | 22uF
C166 | | 1206 | 47uF
C167 | | 1206 | 22uF
C168 | | 1206 | 47uF
C169 | | 0603 | 1uF
C170 | | 0603 | 0.1uF
C171 | | 0603 | 0.1uF
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

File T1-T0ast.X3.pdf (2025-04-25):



24-pin Attachment
for legacy ATX PSU

Power switch
relay; takes over if
CM5 is powered

Opto-Isolator (Single Channel)

CM5 is powered from discrete
regulator in order to allow for
debugging via removal of
connector from J12. If peripherals
draw heavily from 5v_PER, Cm5
should remain unaffected


PCIe_CLK_nREQ | B8 B8

Full-size headerfor PCIEcards. Still
only populated 1x Lane @ Gen2 speed

NB SD signals are only available
on modules without eMMC

4-Pin Male Header(0.100" Pitch)

GPIO3 GPIO4 | GPIO27 GPIO22

GPIO9 GPIO11 | GPIO6





Primary LAN, Passed direct
to filtered RJ45






Designator | LCSCPN | Footprint | Value
C1 | | 1210 | 100uF
C2 | | 1206 | 22nF
C3 | | 0603 | 1uF
C4 | | 0603 | 1uF
C5 | | 1206 | 22nF
C6 | | 0603 | 1uF
C7 | | 1210 | 100uF
C8 | | 0603 | 1uF
C9 | | 0603 | 1uF
C10 | | 1206 | 100uF
C11 | | 1206 | 3.3uF
C12 | | 0603 | 22pF
C13 | | 0603 | 22pF
C14 | | 1206 | 10uF
C15 | | 1206 | 10uF
C16 | | 0603 | 0.1uF
C17 | | 0603 | 100pF
C18 | | 0603 | 100pF
C19 | | 0603 | 1uF
C20 | | 0603 | 0.1uF
C21 | | 1206 | 22uF
C22 | | 1206 | 47uF
C23 | | 0603 | 10uF
C24 | | 0603 | 0.1uF
C25 | | 1206 | 22uF
C26 | | 1206 | 47uF
C27 | | 0603 | 1uF
C28 | | 0603 | 0.1uF
C29 | | 0603 | 1uF
C30 | | 0603 | 0.1uF
C31 | | 0603 | 0.1uF
C32 | | 0603 | 0.1uF
C33 | | 0603 | 0.1uF
C34 | | 0603 | 0.1uF
C35 | | 0603 | 0.1uF
C36 | | 0603 | 0.1uF
C37 | | 0603 | 0.1uF
C38 | | 0603 | 33pF
C39 | | 0603 | 33pF
C40 | | 0603 | 0.1uF
C41 | | 0603 | 1uF
C42 | | 0603 | 1uF
C43 | | 0603 | 1uF
C44 | | 0603 | 1uF
C45 | | 0603 | 1uF
C46 | | 0603 | 1uF
C47 | | 0603 | 1uF
C48 | | 0603 | 1uF
C49 | | 0603 | 1uF
C50 | | 0603 | 1uF
C51 | | 0603 | 0.1uF
C52 | | 0603 | 0.1uF
C53 | | 0603 | 0.1uF
C54 | | 0603 | 0.1uF
C55 | | 0603 | 0.1uF
C56 | | 0603 | 0.1uF
C57 | | 0603 | 0.01uF
C58 | | 0603 | 0.1uF
C59 | | 0603 | 0.01uF
C60 | | 0603 | 0.1uF
C61 | | 0603 | 0.01uF
C62 | | 0603 | 0.1uF
C63 | | 0603 | 0.01uF
C64 | | 0603 | 0.1uF
C65 | | 0603 | 0.1uF
C66 | | 0603 | 0.1uF
C67 | | 0603 | 0.1uF
C68 | | 0603 | 0.1uF
C69 | | 0603 | 0.1uF
C70 | | 0603 | 0.1uF
C71 | | 0603 | 0.1uF
C72 | | 0603 | 0.1uF
C73 | | 0603 | 1uF
C74 | | 0603 | 470nF
C75 | | 0603 | 0.1uF
C76 | | 0603 | 0.1uF
C77 | | 0603 | 1uF
C78 | | 0603 | 0.1uF
C79 | | 0603 | 0.1uF
C80 | | 0603 | 0.1uF
C81 | | 0603 | 0.1uF
C82 | | 0603 | 0.1uF
C83 | | 0603 | 0.1uF
C84 | | 0603 | 0.1uF
C85 | | 0603 | 0.1uF
C86 | | 0603 | 0.1uF
C87 | | 0603 | 0.01uF
C88 | | 0603 | 0.1uF
C89 | | 0603 | 0.1uF
C90 | | 0603 | 0.01uF
C91 | | 0603 | 0.1uF
C92 | | 0603 | 0.1uF
C93 | | 0603 | 0.01uF
C94 | | 0603 | 0.1uF
C95 | | 0603 | 0.1uF
C96 | | 0603 | 0.01uF
C97 | | 0603 | 0.1uF
C98 | | 0603 | 0.1uF
C99 | | 0603 | 0.1uF
C100 | | 0603 | 0.1uF
C101 | | 0603 | 0.1uF
C102 | | 0603 | 0.1uF
C103 | | 0603 | 0.1uF
C104 | | 0603 | 0.1uF
C105 | | 0603 | 0.1uF
C106 | | 0603 | 0.1uF
C107 | | 0603 | 0.1uF
C108 | | 0603 | 0.1uF
C109 | | 0603 | 0.1uF
C110 | | 0603 | 0.1uF
C111 | | 0603 | 0.1uF
C112 | | 0603 | 0.1uF
C113 | | 0603 | 0.1uF
C114 | | 0603 | 0.1uF
C115 | | 0603 | 0.1uF
C116 | | 0603 | 0.1uF
C117 | | 0603 | 0.1uF
C118 | | 0603 | 0.1uF
C119 | | 0603 | 0.1uF
C120 | | 0603 | 0.1uF
C121 | | 0603 | 0.1uF
C122 | | 0603 | 0.1uF
C123 | | 0603 | DNP
C124 | | 0603 | DNP
C125 | | 0603 | 0.1uF
C126 | | 0603 | 0.1uF
C127 | | 0603 | 0.1uF
C128 | | 0603 | 100nF
C129 | | 0603 | 1uF
C130 | | 0603 | 0.1uF
C131 | | 0603 | 0.1uF
C132 | | 0603 | 0.1uF
C133 | | 0603 | 0.01uF
C134 | | 0603 | 0.1uF
C135 | | 0603 | 0.01uF
C136 | | 0603 | 1uF
C137 | | 0603 | 22uF
C138 | | 1206 | 1uF
C139 | | 1206 | 47uF
C140 | | 0603 | 0.1uF
C141 | | 0603 | 0.01uF
C142 | | 0603 | 0.1uF
C143 | | 0603 | 0.01uF
C144 | | 0603 | 0.1uF
C145 | | 0603 | 0.1uF
C146 | | 0603 | 0.1uF
C147 | | 0603 | 0.1uF
C148 | | 0603 | 0.1uF
C149 | | 0603 | 0.1uF
C150 | | 0603 | 0.1uF
C151 | | 0603 | 100nF
C152 | | 0603 | 1uF
C153 | | 0603 | 0.1uF
C154 | | 0603 | 0.1uF
C155 | | 0603 | 1uF
C156 | | 0603 | 22uF
C157 | | 1206 | 1uF
C158 | | 1206 | 47uF
C159 | | 1206 | 22uF
C160 | | 1206 | 47uF
C161 | | 1206 | 22uF
C162 | | 1206 | 47uF
C163 | | 1206 | 22uF
C164 | | 1206 | 47uF
C165 | | 1206 | 22uF
C166 | | 1206 | 47uF
C167 | | 0603 | 1uF
C168 | | 0603 | 0.1uF
C169 | | 0603 | 1uF
C170 | | 0603 | 0.1uF
C171 | | 0603 | 0.1uF
C172 | | 0603 | 0.1uF
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

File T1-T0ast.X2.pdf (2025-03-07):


SD_Card.SchDoc
Micro SD
Passed direct from CM5,
power reg based on IO
module

USB_SATA.SchDoc
2x SATA output
Uses USB3-0 and Sata
brides to translate for
disk drives


24-pin Attachment
for legacy ATX PSU

Power switch
relay; takes over if
CM5 is powered

Opto-Isolator (Single Channel)

CM5 is powered from discrete
regulator in order to allow for
debugging via removal of
connector from J12. If peripherals
draw heavily from 5v_PER, Cm5
should remain unaffected


PCIe_CLK_nREQ | B8 B8

Full-size headerfor PCIEcards. Still
only populated 1x Lane @ Gen2 speed

NB SD signals are only available
on modules without eMMC

4-Pin Male Header(0.100" Pitch)





Primary LAN, Passed direct
to filtered RJ45





Designator | LCSCPN | Footprint | Value
C1 | | 0603 | 1uF
C2 | | 0603 | 1uF
C3 | | 0603 | 0.1uF
C4 | | 0603 | 1uF
C5 | | 0603 | 0.1uF
C6 | | 1206 | 22uF
C7 | | 1206 | 47uF
C8 | | 1206 | 22uF
C9 | | 1206 | 47uF
C10 | | 1206 | 22uF
C11 | | 0603 | 1uF
C12 | | 0603 | 0.1uF
C13 | | 0603 | 0.1uF
C14 | | 0603 | 0.1uF
C15 | | 0603 | 0.1uF
C16 | | 0603 | 0.1uF
C17 | | 0603 | 0.1uF
C18 | | 0603 | 0.1uF
C19 | | 0603 | 0.1uF
C21 | | 0603 | 0.1uF
C22 | | 0603 | 0.1uF
C23 | | 0603 | 0.1uF
C24 | | 0603 | 0.1uF
C26 | | 0603 | 0.1uF
C27 | | 0603 | 0.1uF
C28 | | 0603 | 0.1uF
C29 | | 0603 | 0.1uF
C30 | | 0603 | 0.1uF
C31 | | 0603 | 0.1uF
C32 | | 0603 | 0.1uF
C33 | | 0603 | 0.1uF
C34 | | 0603 | 0.1uF
C35 | | 0603 | 0.1uF
C36 | | 0603 | 0.1uF
C37 | | 0603 | 0.1uF
C38 | | 0603 | 0.1uF
C39 | | 0603 | 0.1uF
C40 | | 0603 | 0.1uF
C41 | | 0603 | 0.1uF
C42 | | 0603 | 0.1uF
C43 | | 0603 | 0.1uF
C44 | | 0603 | 0.1uF
C45 | | 0603 | 0.1uF
C46 | | 0603 | 0.1uF
C47 | | 0603 | 0.1uF
C48 | | 0603 | 0.1uF
C49 | | 0603 | 0.1uF
C50 | | 0603 | 0.1uF
C51 | | 0603 | 0.1uF
C52 | | 0603 | 0.1uF
C53 | | 0603 | 1uF
C54 | | 0603 | 1uF
C55 | | 0603 | 1uF
C56 | | 0603 | 1uF
C57 | | 0603 | 1uF
C58 | | 0603 | 1uF
C59 | | 0603 | 1uF
C60 | | 0603 | 1uF
C61 | | 0603 | 1uF
C62 | | 0603 | 1uF
C63 | | 0603 | 0.1uF
C64 | | 0603 | 0.1uF
C65 | | 0603 | 0.1uF
C66 | | 0603 | DNP
C67 | | 0603 | DNP
C68 | | 0603 | 1uF
C69 | | 0603 | 0.1uF
C70 | | 0603 | 0.1uF
C72 | | 0603 | 0.1uF
C73 | | 1206 | 22uF
C74 | | 0603 | 0.1uF
C75 | | 1206 | 47uF
C76 | | 0603 | 0.1uF
C77 | | 0603 | 0.1uF
C78 | | 1206 | 47uF
C79 | | 0603 | 0.1uF
C80 | | 0603 | 0.1uF
C81 | | 0603 | 0.1uF
C82 | | 0603 | 0.1uF
C83 | | 0603 | 0.1uF
C84 | | 0603 | 0.1uF
C85 | | 0603 | 0.1uF
C86 | | 1206 | 22uF
C87 | | 0603 | 0.1uF
C88 | | 1206 | 47uF
C89 | | 0603 | 0.1uF
C90 | | 0603 | 0.1uF
C91 | | 0603 | 0.1uF
C92 | | 0603 | 0.1uF
C93 | | 0603 | 0.1uF
C94 | | 0603 | 0.1uF
C95 | | 0603 | DNP
C96 | | 0603 | DNP
C97 | | 0603 | 0.1uF
C98 | | 0603 | 10uF
C99 | | 0603 | 0.1uF
C100 | | 1206 | 22uF
C101 | | 1206 | 47uF
C102 | | 0603 | 0.01uF
C103 | | 0603 | 0.01uF
C104 | | 0603 | 0.01uF
C105 | | 0603 | 0.01uF
C106 | | 0603 | 0.1uF
C107 | | 0603 | 0.1uF
C108 | | 0603 | 0.1uF
C109 | | 0603 | 0.1uF
C110 | | 0603 | 0.1uF
C111 | | 0603 | 0.1uF
C112 | | 0603 | 0.01uF
C113 | | 0603 | 0.1uF
C114 | | 0603 | 0.01uF
C115 | | 0603 | 0.1uF
C116 | | 0603 | 100nF
C117 | | 0603 | 0.01uF
C118 | | 0603 | 0.1uF
C119 | | 0603 | 0.01uF
C120 | | 0603 | 0.1uF
C121 | | 0603 | 0.1uF
C122 | | 0603 | 0.1uF
C123 | | 0603 | 1uF
C124 | | 0603 | 22uF
C125 | | 1206 | 1uF
C126 | | 1206 | 47uF
C127 | | 0603 | 0.1uF
C128 | | 0603 | 0.1uF
C129 | | 0603 | 0.1uF
C130 | | 0603 | 0.1uF
C131 | | 0603 | 0.1uF
C132 | | 0603 | 0.1uF
C133 | | 0603 | 100nF
C134 | | 0603 | 1uF
C135 | | 0603 | 22uF
C136 | | 1206 | 1uF
C137 | | 1206 | 47uF
C138 | | 1210 | 100uF
C139 | | 1206 | 22nF
C140 | | 0603 | 1uF
C141 | | 0603 | 1uF
C142 | | 0603 | 1uF
C143 | | 1206 | 22nF
C144 | | 0603 | 100nF
C145 | | 0603 | 1uF
C146 | | 0603 | 22uF
C147 | | 1206 | 1uF
C148 | | 1206 | 47uF
C149 | | 0603 | 1uF
C150 | | 1210 | 100uF
C151 | | 0603 | 1uF
C152 | | 0603 | 1uF
C153 | | 1206 | 100uF
C154 | | 1206 | 3.3uF
C155 | | 0603 | 22pF
C156 | | 0603 | 22pF
C157 | | 1206 | 10uF
C158 | | 1206 | 10uF
C159 | | 0603 | 0.1uF
C160 | | 0603 | 100pF
C161 | | 0603 | 100pF
C162 | | 0603 | 1uF
C163 | | 0603 | 1uF
C164 | | 0603 | 0.1uF
C165 | | 0603 | 0.1uF
C166 | | 0603 | 0.1uF
C167 | | 0603 | 0.1uF
C168 | | 0603 | 0.1uF
C169 | | 0603 | 0.1uF
C170 | | 0603 | 0.1uF
C171 | | 0603 | 0.1uF
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

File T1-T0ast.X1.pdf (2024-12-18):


SD_Card.SchDoc
Micro SD
Passed direct from CM5,
power reg based on IO
module

USB_SATA.SchDoc
2x SATA output
Uses USB3-0 and Sata
brides to translate for
disk drives


24-pin Attachment
for legacy ATX PSU

Power switch
relay; takes over if
CM5 is powered

Opto-Isolator (Single Channel)

CM5 is powered from discrete
regulator in order to allow for
debugging via removal of
connector from J12. If peripherals
draw heavily from 5v_PER, Cm5
should remain unaffected


Full-size headerfor PCIEcards. Still
only populated 1x Lane @ Gen2 speed

NB SD signals are only available
on modules without eMMC

C59 | Value: 1uF
C61 | Value: 1uF | HDMI0_CLK_P HDMI0_CLK_N

4-Pin Male Header(0.100" Pitch)




Primary LAN, Passed direct
to filtered RJ45


VCC 11 VREG_OUT 12 EQ/SCL 13 ERC/SDA 14




Designator | LCSCPN | Footprint | Value
C1 | | 0603 | 1uF
C2 | | 0603 | 1uF
C3 | | 0603 | 1uF
C4 | | 0603 | DNP
C5 | | 0603 | DNP
C6 | | 1206 | 22uF
C7 | | 1206 | 47uF
C8 | | 1206 | 22uF
C9 | | 1206 | 47uF
C10 | | 1206 | 22uF
C11 | | 0603 | 1uF
C12 | | 0603 | 0.1uF
C13 | | 0603 | 0.1uF
C14 | | 0603 | 0.1uF
C15 | | 0603 | 0.1uF
C16 | | 0603 | 0.1uF
C17 | | 0603 | 0.1uF
C18 | | 0603 | 0.1uF
C19 | | 0603 | 0.1uF
C20 | | 0603 | 1uF
C21 | | 0603 | 0.1uF
C22 | | 0603 | 0.1uF
C23 | | 0603 | 0.1uF
C24 | | 0603 | 0.1uF
C25 | | 0603 | .1uF
C26 | | 0603 | 0.1uF
C27 | | 0603 | 0.1uF
C28 | | 0603 | 0.1uF
C29 | | 0603 | 0.1uF
C30 | | 0603 | 0.1uF
C31 | | 0603 | 0.1uF
C32 | | 0603 | 0.1uF
C33 | | 0603 | 0.1uF
C34 | | 0603 | 0.1uF
C35 | | 0603 | 0.1uF
C36 | | 0603 | 0.1uF
C37 | | 0603 | 0.1uF
C38 | | 0603 | 0.1uF
C39 | | 0603 | 0.1uF
C40 | | 0603 | 0.1uF
C41 | | 0603 | 0.1uF
C42 | | 0603 | 0.1uF
C43 | | 0603 | 0.1uF
C44 | | 0603 | 0.1uF
C45 | | 0603 | 0.1uF
C46 | | 0603 | 0.1uF
C47 | | 0603 | 0.1uF
C48 | | 0603 | 0.1uF
C49 | | 0603 | 0.1uF
C50 | | 0603 | 0.1uF
C51 | | 0603 | 0.1uF
C52 | | 0603 | 0.1uF
C53 | | 0603 | 1uF
C54 | | 0603 | 1uF
C55 | | 0603 | 1uF
C56 | | 0603 | 1uF
C57 | | 0603 | 1uF
C58 | | 0603 | 1uF
C59 | | 0603 | 1uF
C60 | | 0603 | 1uF
C61 | | 0603 | 1uF
C62 | | 0603 | 1uF
C63 | | 0603 | 0.1uF
C64 | | 0603 | 0.1uF
C65 | | 0603 | 0.1uF
C66 | | 0603 | DNP
C67 | | 0603 | DNP
C68 | | 0603 | 1uF
C69 | | 0603 | 0.1uF
C70 | | 0603 | 0.1uF
C71 | | 0603 | 1uF
C72 | | 0603 | 0.1uF
C73 | | 1206 | 22uF
C74 | | 0603 | 0.1uF
C75 | | 1206 | 47uF
C76 | | 0603 | 0.1uF
C77 | | 0603 | 0.1uF
C78 | | 1206 | 47uF
C79 | | 0603 | 0.1uF
C80 | | 0603 | 0.1uF
C81 | | 0603 | 0.1uF
C82 | | 0603 | 0.1uF
C83 | | 0603 | 0.1uF
C84 | | 0603 | 0.1uF
C85 | | 0603 | 0.1uF
C86 | | 1206 | 22uF
C87 | | 0603 | 0.1uF
C88 | | 1206 | 47uF
C89 | | 0603 | 0.1uF
C90 | | 0603 | 0.1uF
C91 | | 0603 | 0.1uF
C92 | | 0603 | 0.1uF
C93 | | 0603 | 0.1uF
C94 | | 0603 | 0.1uF
C95 | | 0603 | DNP
C96 | | 0603 | DNP
C97 | | 0603 | 0.1uF
C98 | | 0603 | 10uF
C99 | | 0603 | 0.1uF
C100 | | 1206 | 22uF
C101 | | 1206 | 47uF
C102 | | 0603 | 0.01uF
C103 | | 0603 | 0.01uF
C104 | | 0603 | 0.01uF
C105 | | 0603 | 0.01uF
C106 | | 0603 | 0.1uF
C107 | | 0603 | 0.1uF
C108 | | 0603 | 0.1uF
C109 | | 0603 | 0.1uF
C110 | | 0603 | 0.1uF
C111 | | 0603 | 0.1uF
C112 | | 0603 | 0.01uF
C113 | | 0603 | 0.1uF
C114 | | 0603 | 0.01uF
C115 | | 0603 | 0.1uF
C116 | | 0603 | 100nF
C117 | | 0603 | 0.01uF
C118 | | 0603 | 0.1uF
C119 | | 0603 | 0.01uF
C120 | | 0603 | 0.1uF
C121 | | 0603 | 0.1uF
C122 | | 0603 | 0.1uF
C123 | | 0603 | 1uF
C124 | | 0603 | 22uF
C125 | | 1206 | 1uF
C126 | | 1206 | 47uF
C127 | | 0603 | 0.1uF
C128 | | 0603 | 0.1uF
C129 | | 0603 | 0.1uF
C130 | | 0603 | 0.1uF
C131 | | 0603 | 0.1uF
C132 | | 0603 | 0.1uF
C133 | | 0603 | 100nF
C134 | | 0603 | 1uF
C135 | | 0603 | 22uF
C136 | | 1206 | 1uF
C137 | | 1206 | 47uF
C140 | | 0603 | 1uF
C144 | | 0603 | 100nF
C145 | | 0603 | 1uF
C146 | | 0603 | 22uF
C147 | | 1206 | 1uF
C148 | | 1206 | 47uF
CASE_FAN | | TSW-104-07-T-S
CPU_FAN | | TSW-104-07-T-S
F1 | C883112 | 0805
F2 | C883112 | 0805
F3 | C883112 | 0805
F4 | C883112 | 0805
F5 | C883112 | 0805
F6 | C883112 | 0805
F7 | C883112 | 0805
F8 | C883112 | 0805
F9 | C883112 | 0805
F10 | C883112 | 0805
F11 | C883112 | 0805
FB1 | C275486 | 0603
FB2 | C275486 | 0603
FB3 | C275486 | 0603
FB4 | C275486 | 0603
FB5 | C2926396 | 1206
FB6 | C2926396 | 1206
FB7 | C2926396 | 1206
FB8 | C2926396 | 1206
FB9 | C275486 | 0603
FB10 | C275486 | 0603
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

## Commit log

2024-12-18 Initial Commit
    First prototype design for Cm5-MiniITX board
    [Block Diagram.SchDoc, Docking_Connection.SchDoc, HDMI.SchDoc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]
2025-01-13 Add files, schematic change, add functionality
    -Replace 1x FUSB with 1x FAudio
    -Replace 2x-4Pin FUSB connector with 1x-10pin connector footprint
    -Add USB-Audio subcircuit
    -Add Tach signal to CPU fan
    -Add CM5 active cooler connector
    [Block Diagram.SchDoc, Docking_Connection.SchDoc, T1-T0ast.X1.PrjPcb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]
2025-03-07 Rev X2 update
    - remove equalizer from HDMI1
    [HDMI.SchDoc]
2025-03-07 Rev X2 update
    - Replace 40pin GPIO header with footprint of rPiZero
    - Replace 4-pin disable header with 10-pin; add nRPI & Pwr
    [Docking_Connection.SchDoc]
2025-03-07 Rev X2 update
    - add 0.5s delay to power-latch relay
    [Power_Regulation.SchDoc]
2025-03-07 Rev X2 update
    - add 1.5k pull-up on D_P to VDD
    [USB_Audio.SchDoc]
2025-03-07 Rev X2 update
    - add eeprom to both bridges
    - add 0.5s delay to GRST
    [USB_SATA.SchDoc]
2025-03-07 Rev X2 update
    - switch to USB2517-JZX as hub
    [USB2_Replication.SchDoc]
2025-03-07 Rev X2 Update
    - reference updates to schematics, PCBA, and BOM
2025-03-11 Fix reset/resonators
    found issues in boot sequence where crystal resonance would not stabilize right away, so added caps and 1M res between terminals
    Changed VB-detect voltage divider to 10K pull-up to 3.3V
    Changed reset pullup resistor from 100k to 10k
    [USB2_Replication.SchDoc]
2025-04-06 X1 refresh
    Re-upload final X1 design after restructuring repo
    [Block Diagram.SchDoc, Docking_Connection.SchDoc, HDMI.SchDoc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]
2025-04-06 X2 Refresh
    Re-upload final X2 design after restructuring repo
    [Block Diagram.SchDoc, Docking_Connection.SchDoc, HDMI.SchDoc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]
2025-04-06 X3 Refresh
    Re-upload X3 design files after restructuring repo;
    PcbDoc file was too big, so it is in a compressed zip
    [Docking_Connection.SchDoc, HDMI.SchDoc, M2_USB_SATA.SchDoc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]
2025-04-06 upload assembly files
    Each revision's assembly files are discretely zipped such that they can be uploaded to JLC or PCBway as-is for bare PCB, and the requisite BOM & Pick&Place can be extracted therein.
2025-05-08 Add Current X4 design
    Zipped due to filesize limitation
